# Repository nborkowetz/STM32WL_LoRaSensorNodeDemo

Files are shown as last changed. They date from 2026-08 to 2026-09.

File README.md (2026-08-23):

# STM32WL LoRaWAN Sensor Node

Low-power LoRaWAN sensor node based on the **STM32WL55**, originally designed as a prototype platform for distributed water-monitoring applications.

The original goal was not to build a complete water-quality instrument around a fixed set of probes, but to validate the **overall sensing and communication architecture** first: a battery-powered node, generic sensor interfaces, LoRaWAN connectivity, a local gateway and a self-hosted backend.

Water monitoring may involve very different sensors and analog front-ends depending on the quantity being measured. For this reason, the sensing layer is intentionally kept generic while the project focuses on validating the reusable parts of the system.

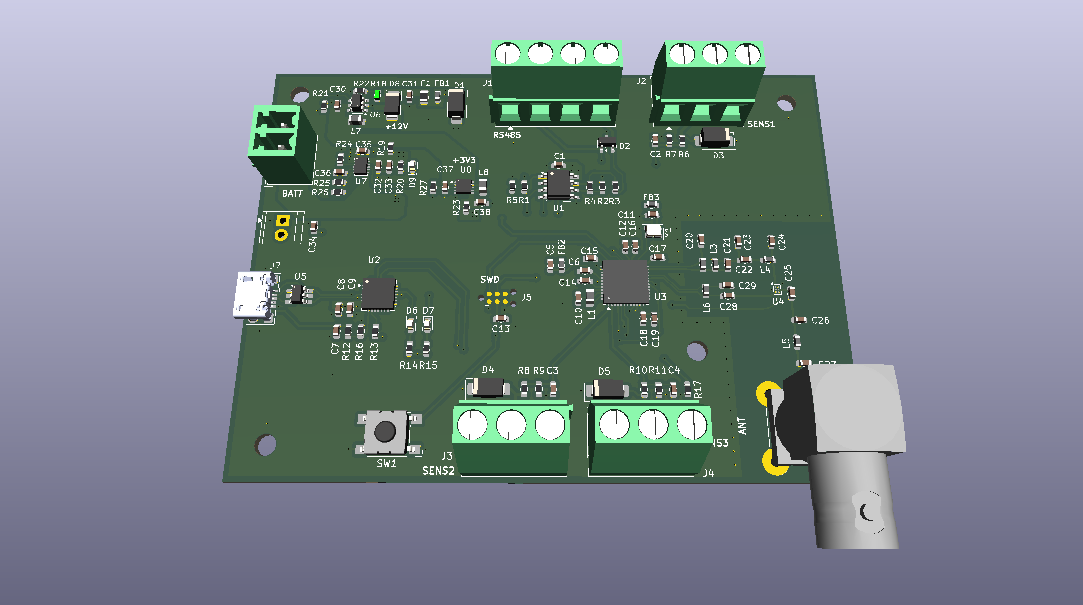
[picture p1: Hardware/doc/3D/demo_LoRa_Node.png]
Board 3D render


## Concept

The prototype is intended as a test platform for the complete data path:

```text
Sensor / External AFE
        |
   Analog / RS-485
        |
        v
   STM32WL55 Node
        |
      LoRaWAN
        |
        v
   Dragino Gateway
        |
        v
    ChirpStack
        |
       MQTT
        |
        v
   Backend / Web UI
```

The custom node provides a small set of generic interfaces:

- 3× protected and filtered analog inputs
- RS-485 interface
- Switchable 12 V sensor supply
- STM32WL55 integrated Sub-GHz radio
- USB-UART debug interface
- Battery-powered / low-power operation

Sensor-specific amplification, isolation or signal conditioning can be added externally when required.

This allows the LoRaWAN architecture, power-management strategy and backend to be developed independently from the final choice of water-quality sensors.

## Firmware

The firmware is being developed around a low-power, event-driven architecture with:

- periodic sensor acquisition
- timer-triggered ADC sampling with DMA
- digital filtering / processing
- asynchronous UART / RS-485 communication
- sensor power sequencing and warm-up
- deep-sleep and periodic wake-up
- periodic LoRaWAN uplinks
- UART debug console
- error handling and watchdog supervision

Typical measurement cycle:

```text
Sleep -> Sensor ON -> Warm-up -> Acquire -> Process
      -> Sensor OFF -> LoRaWAN TX (if scheduled) -> Sleep
```

Firmware development and LoRaWAN validation are currently performed using an **STM32WL55 development board**. The custom PCB has been designed but has not yet been fabricated.

Synthetic sensor values can be injected during development to validate payload generation and the complete communication path without depending on the final sensing hardware.

## LoRaWAN Infrastructure

A second goal of the project is to make the LoRaWAN test environment **reproducible and easy to deploy**, instead of relying on a manually configured development machine.

The planned local infrastructure consists of:

- Dragino LoRaWAN gateway
- ChirpStack network server
- Mosquitto MQTT broker
- containerized deployment with Docker Compose
- deployment / provisioning scripts
- Python / FastAPI backend for receiving, storing and visualizing measurements

The intended workflow is:

```text
docker compose up
        |
        v
ChirpStack + MQTT services
        |
        v
Automated provisioning
        |
        v
Gateway / device registration
        |
        v
End-to-end LoRaWAN test
```

Configuration files and scripts are kept in the repository so that the test environment can be recreated from a clean machine with minimal manual configuration.

The backend consumes application data exposed by ChirpStack through MQTT; the STM32 node itself only produces the application payload and remains independent from MQTT or the backend implementation.

## Repository Structure

```text
.
├── Hardware/          # KiCad schematic, PCB and documentation
├── Firmware/          # STM32WL55 firmware
├── Infrastructure/    # ChirpStack / MQTT / Docker deployment
├── Tools/             # Python utilities and provisioning tools
└── README.md
```

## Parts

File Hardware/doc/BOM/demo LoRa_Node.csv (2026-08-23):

Id | Designator | Footprint | Quantity | Designation | Supplier and ref
1 | BT1 | PhoenixContact_MCV_1,5_2-G-3.81_1x02_P3.81mm_Vertical | 1 | Battery
2 | C1, C2, C3, C4, C6, C7, C9, C11, C13, C14, C15, C16, C17, C18, C35, C36 | C_0603_1608Metric | 16 | 100n
3 | C5, C8, C10, C19, C32 | C_0603_1608Metric | 5 | 4u7
4 | C12 | C_0603_1608Metric | 1 | 470n
5 | C20, C22, C25 | C_0603_1608Metric | 3 | 68p
6 | C21 | C_0603_1608Metric | 1 | 4p3
7 | C23 | C_0603_1608Metric | 1 | 15p
8 | C24 | C_0603_1608Metric | 1 | 5p6
9 | C26, C27 | C_0603_1608Metric | 2 | 6p8
10 | C28 | C_0603_1608Metric | 1 | 3p6
11 | C29 | C_0603_1608Metric | 1 | 4p7
12 | C30, C31, C33, C38 | C_0603_1608Metric | 4 | 22u
13 | C34, C37 | C_0603_1608Metric | 2 | 10u
14 | D1 | D_SMA | 1 | SMAJ12CA
15 | D2 | SOT-23 | 1 | SM712_SOT23
16 | D3, D4, D5 | D_SMA | 3 | SMAJ6.0CA
17 | D6, D7, D9 | LED_0603_1608Metric | 3 | LED
18 | D8 | D_SOD-128 | 1 | SB120
19 | F1 | Fuse_0805_2012Metric | 1 | 200mA
20 | FB1, FB2, FB3 | L_0603_1608Metric | 3 | 600Ohm@10MHz
21 | J1 | TerminalBlock_Phoenix_MKDS-1,5-4-5.08_1x04_P5.08mm_Horizontal | 1 | Screw_Terminal_01x04
22 | J2, J3, J4 | TerminalBlock_Phoenix_MKDS-1,5-3-5.08_1x03_P5.08mm_Horizontal | 3 | Screw_Terminal_01x03
23 | J6 | BNC_TEConnectivity_1478035_Horizontal | 1 | Conn_Coaxial
24 | J7 | Amphenol usb micro connector | 1 | USB_B_Micro
25 | J8 | TerminalBlock_TE_282834-2_1x02_P2.54mm_Horizontal | 1 | Conn_01x02
26 | L1 | L_0805_2012Metric | 1 | 15u
27 | L2 | L_0603_1608Metric | 1 | 56n
28 | L3 | L_0603_1608Metric | 1 | 6n8
29 | L4, L5 | L_0603_1608Metric | 2 | 16n
30 | L6 | L_0603_1608Metric | 1 | 33n
31 | L7 | L_0805_2012Metric | 1 | 10u
32 | L8 | L_0805_2012Metric | 1 | 2u2
33 | R1, R5, R6, R8, R10, R22 | R_0603_1608Metric | 6 | 10k
34 | R2, R3 | R_0603_1608Metric | 2 | 10
35 | R4 | R_0603_1608Metric | 1 | 120
36 | R7, R9, R11 | R_0603_1608Metric | 3 | 16k2
37 | R12 | R_0603_1608Metric | 1 | 46k4
38 | R13, R14, R15, R20, R24 | R_0603_1608Metric | 5 | 1k
39 | R16, R17, R21, R26 | R_0603_1608Metric | 4 | 100k
40 | R18 | R_0603_1608Metric | 1 | 191k
41 | R19, R23 | R_0603_1608Metric | 2 | 0
42 | R25 | R_0603_1608Metric | 1 | 490k
43 | R27 | R_0603_1608Metric | 1 | 36k5
44 | SW1 | SW_SPST_Omron_B3FS-100xP | 1 | SW_Omron_B3FS
45 | U1 | SOIC-8_3.9x4.9mm_P1.27mm | 1 | THVD1400D
46 | U2 | QFN-28-1EP_5x5mm_P0.5mm_EP3.35x3.35mm | 1 | CP2102N-Axx-xQFN28
47 | U3 | QFN-48-1EP_7x7mm_P0.5mm_EP5.6x5.6mm | 1 | STM32WL55CCUx
48 | U4 | Infineon_PG-TSNP-6-10_0.7x1.1mm_0.7x1.1mm_P0.4mm | 1 | BGS12WN6E6327
49 | U5 | SOT-23-6_Handsoldering | 1 | WE-TVS-82400102
50 | U6 | SOT-23-6 | 1 | MT3608
51 | U7 | WSON-10-1EP_2x3mm_P0.5mm_EP0.84x2.4mm_ThermalVias | 1 | BQ25071
52 | U8 | WSON-10-1EP_2.5x2.5mm_P0.5mm_EP1.2x2mm_ThermalVias | 1 | TPS63900
53 | Y1 | Oscillator_SMD_SeikoEpson_SG210-4Pin_2.5x2.0mm | 1 | SG-210STF 32MHz

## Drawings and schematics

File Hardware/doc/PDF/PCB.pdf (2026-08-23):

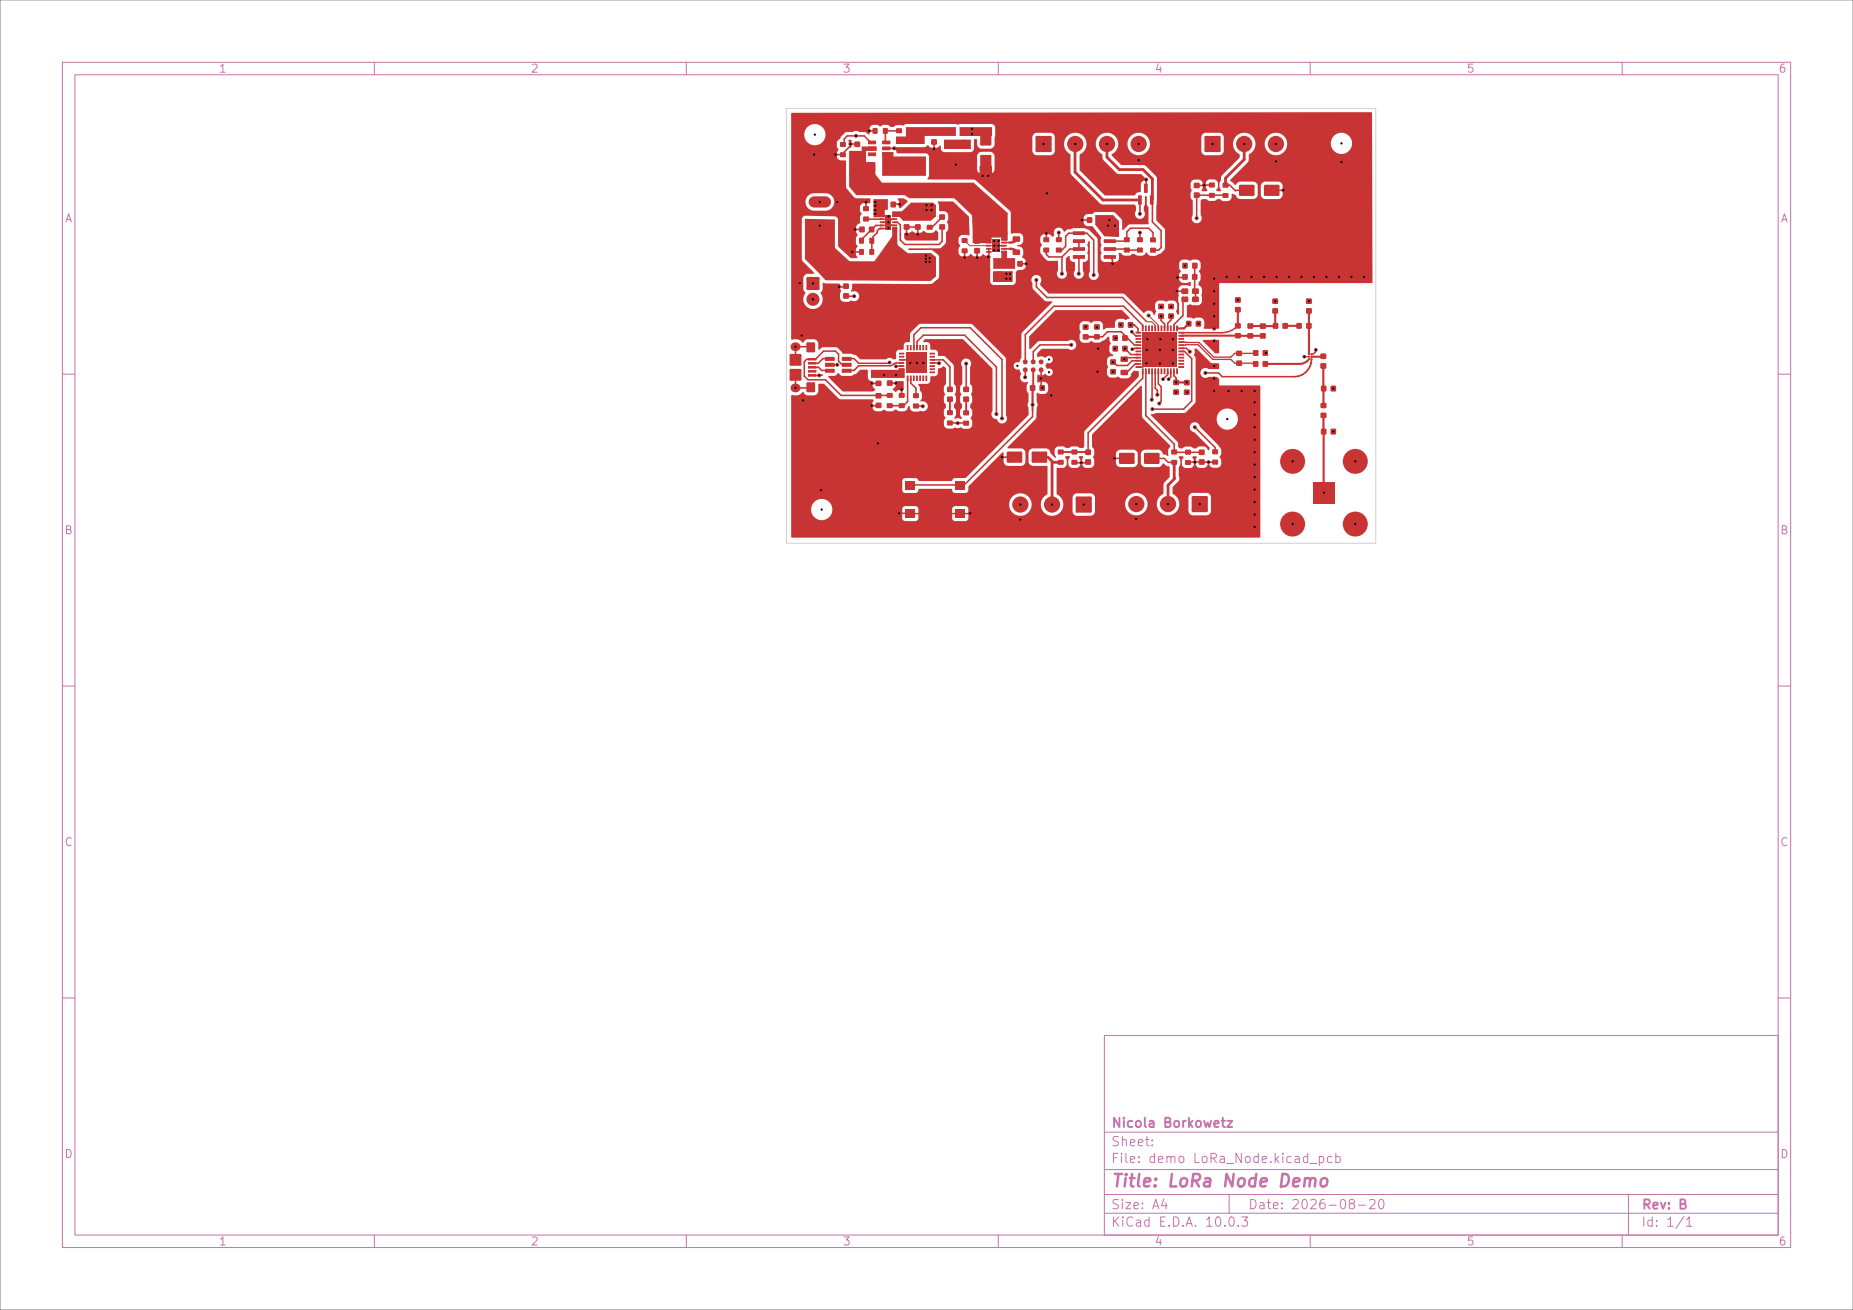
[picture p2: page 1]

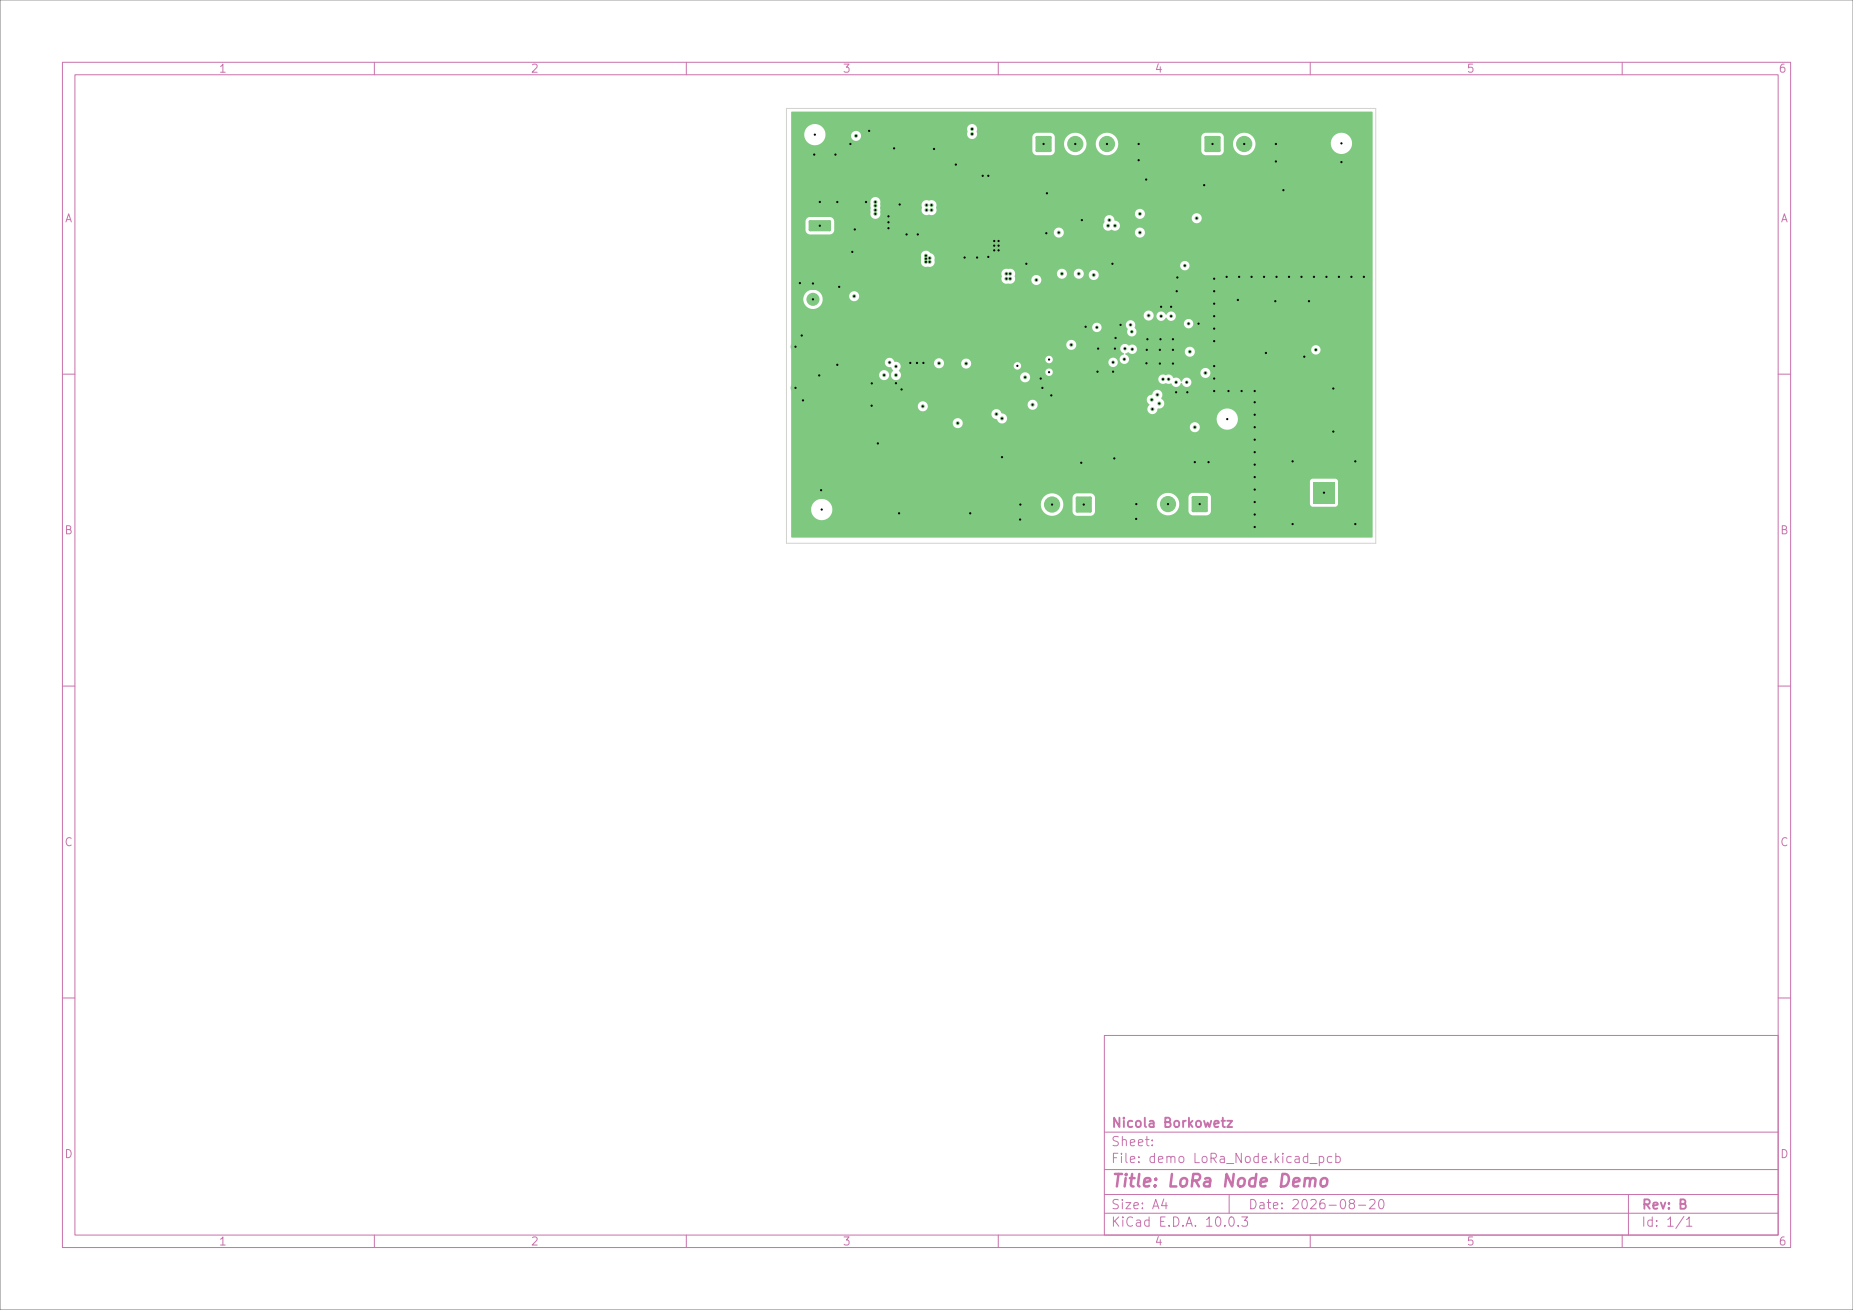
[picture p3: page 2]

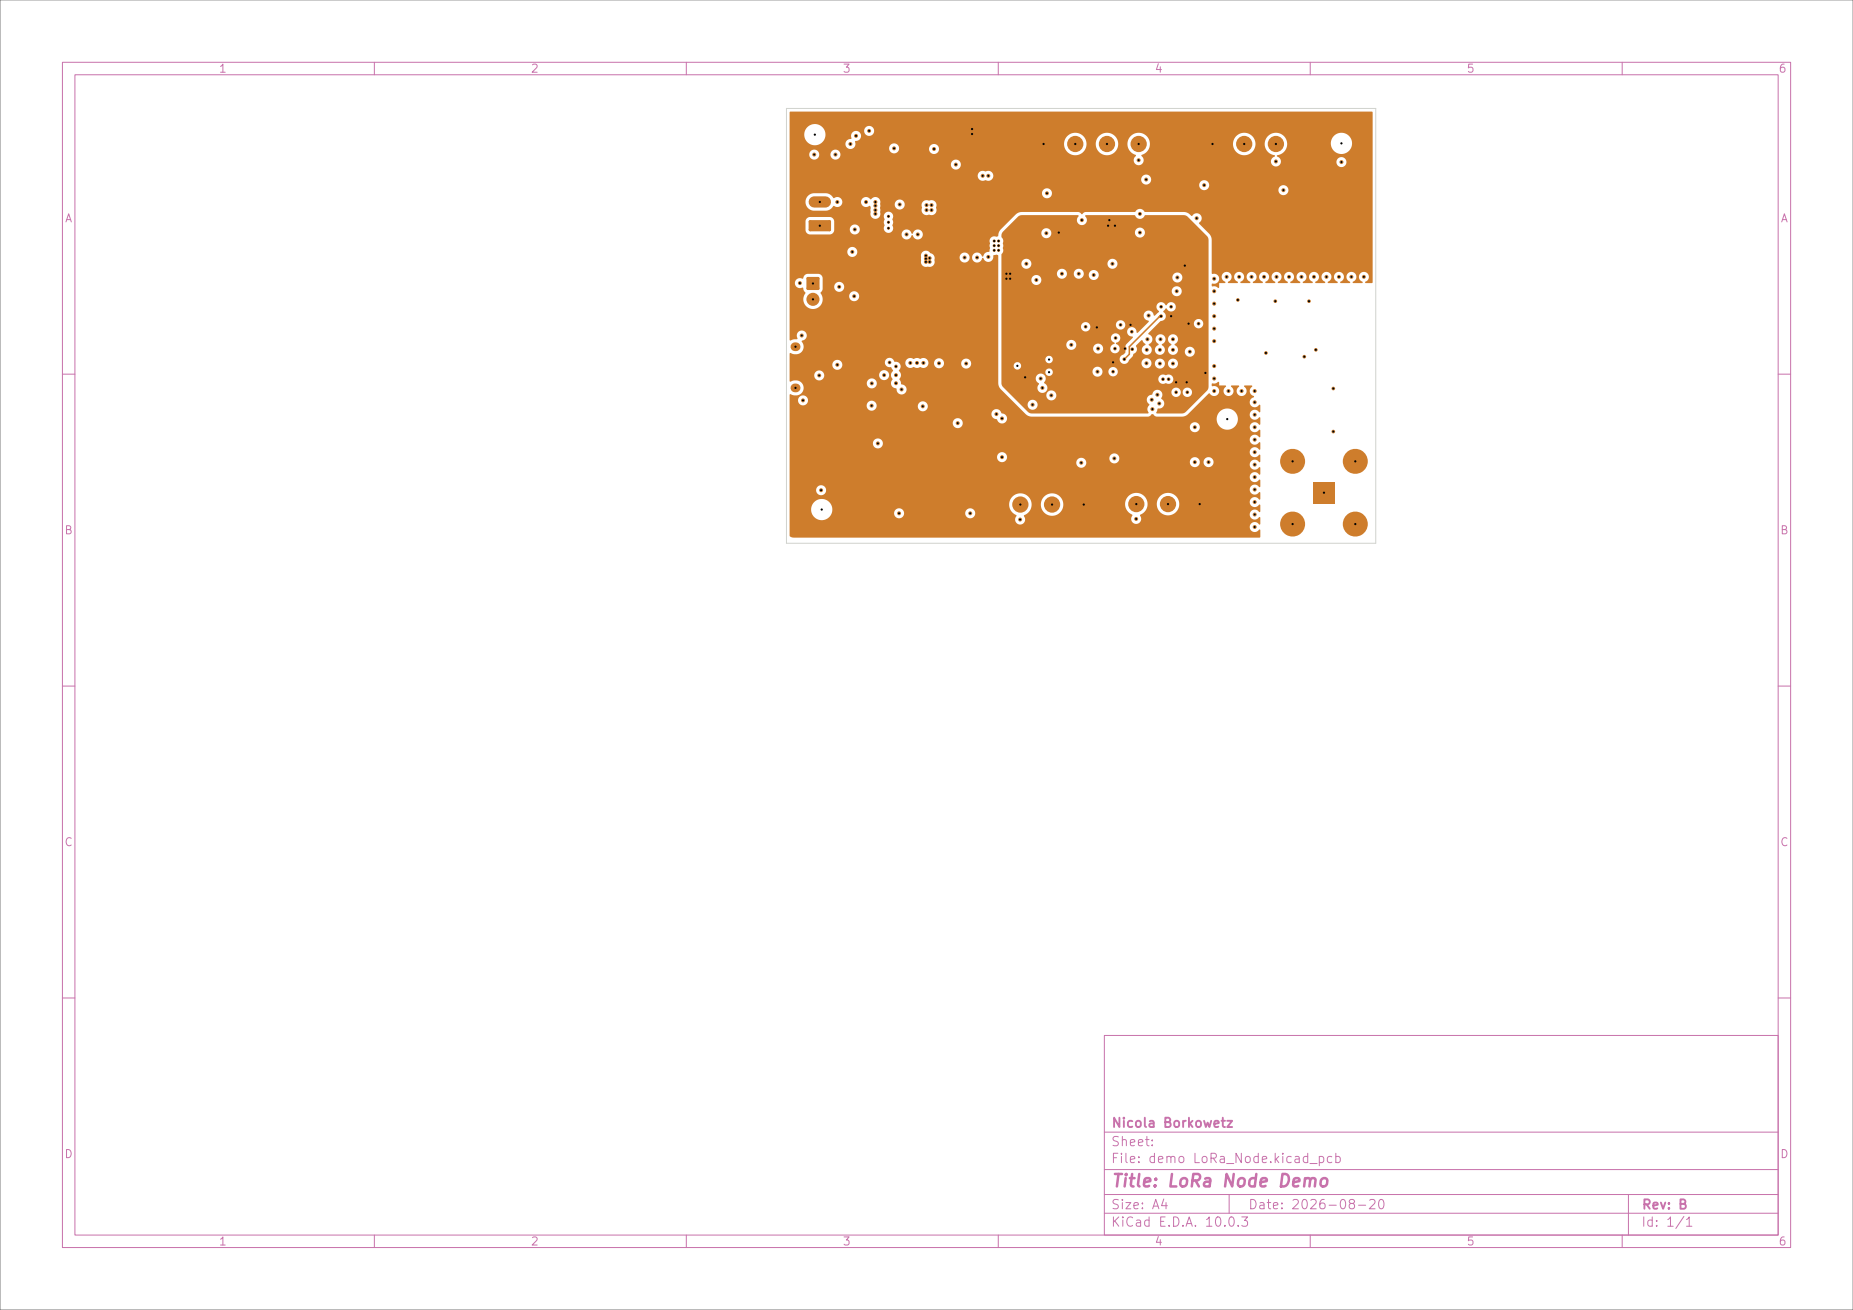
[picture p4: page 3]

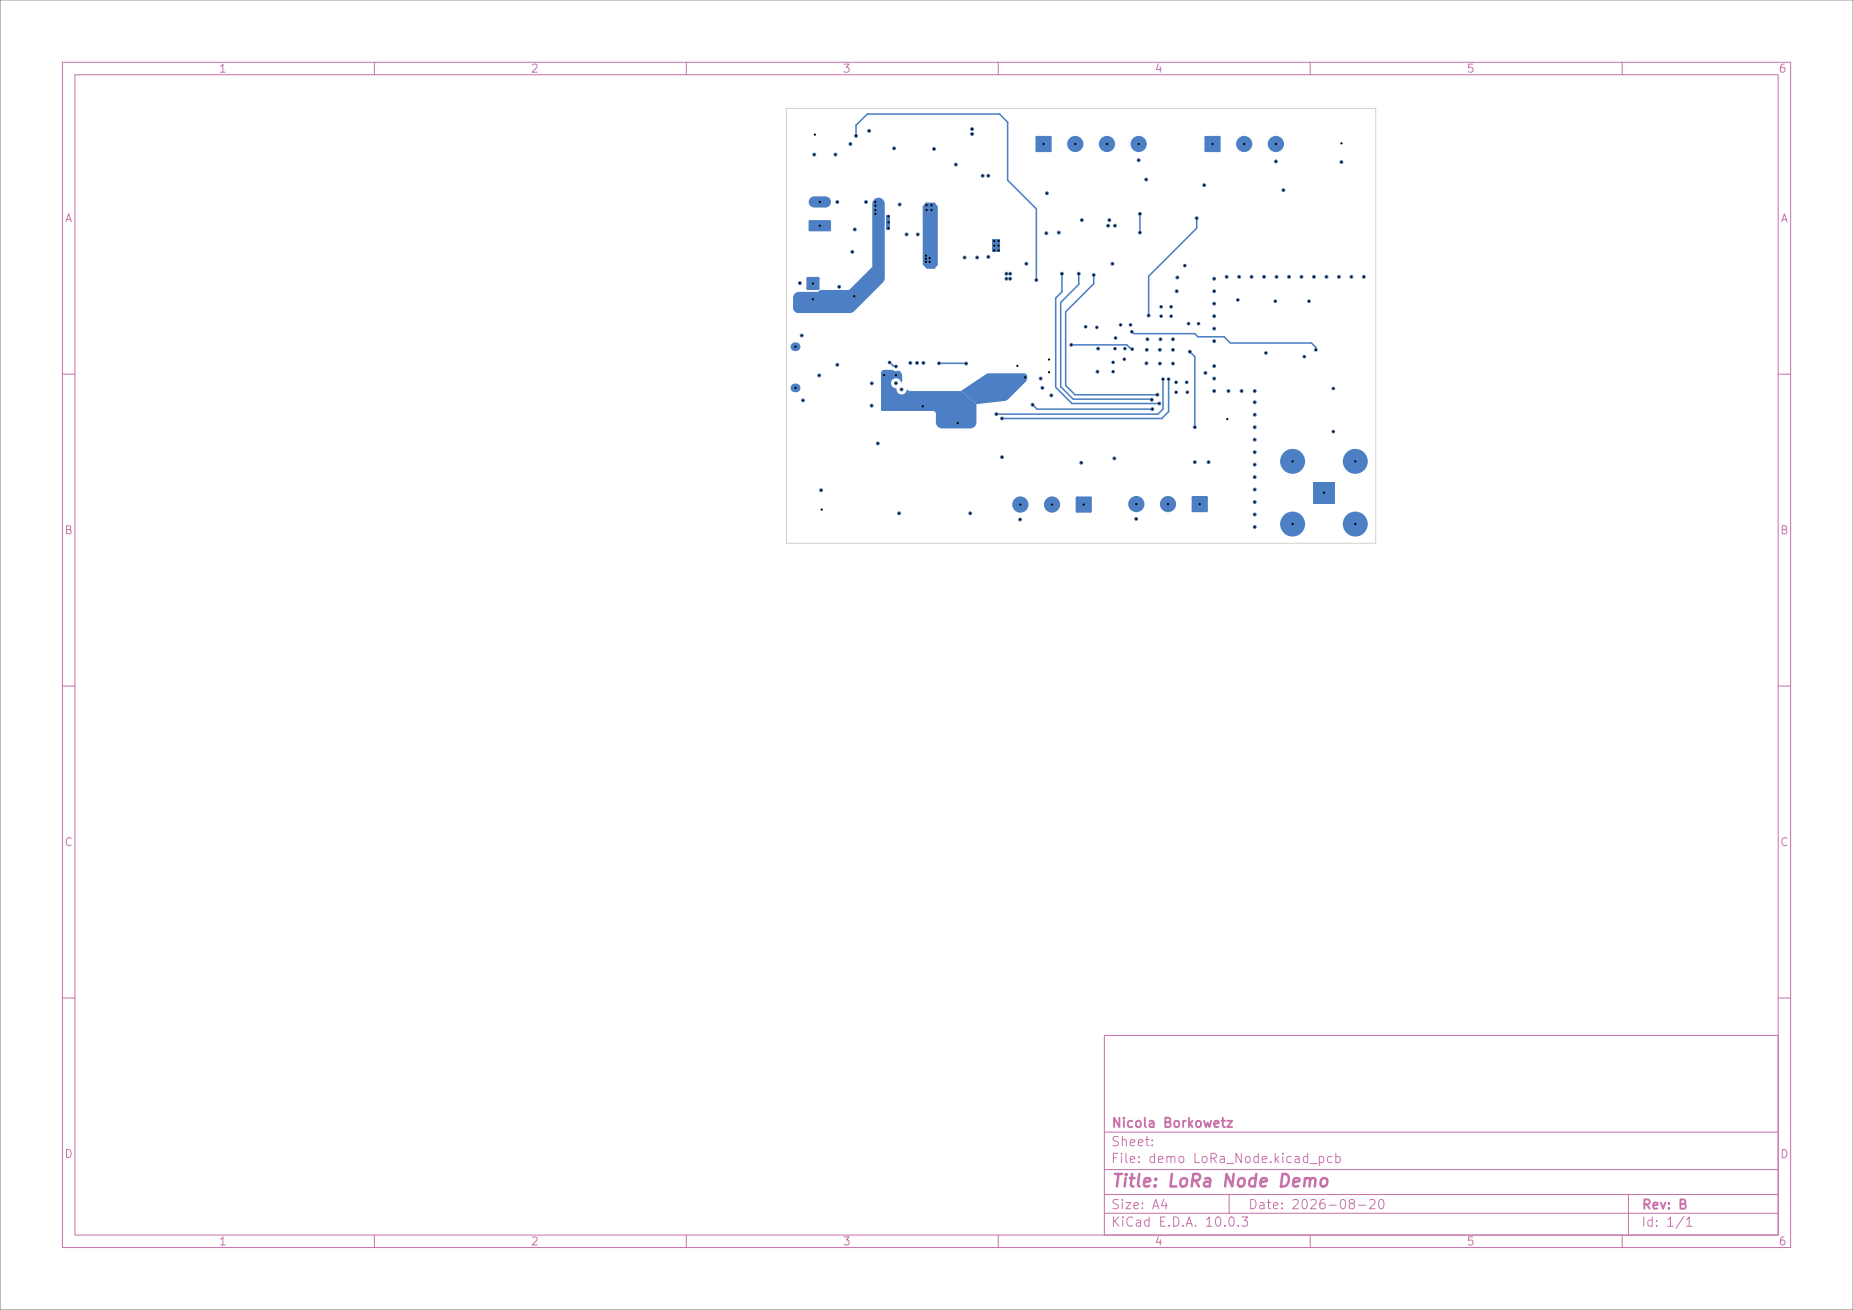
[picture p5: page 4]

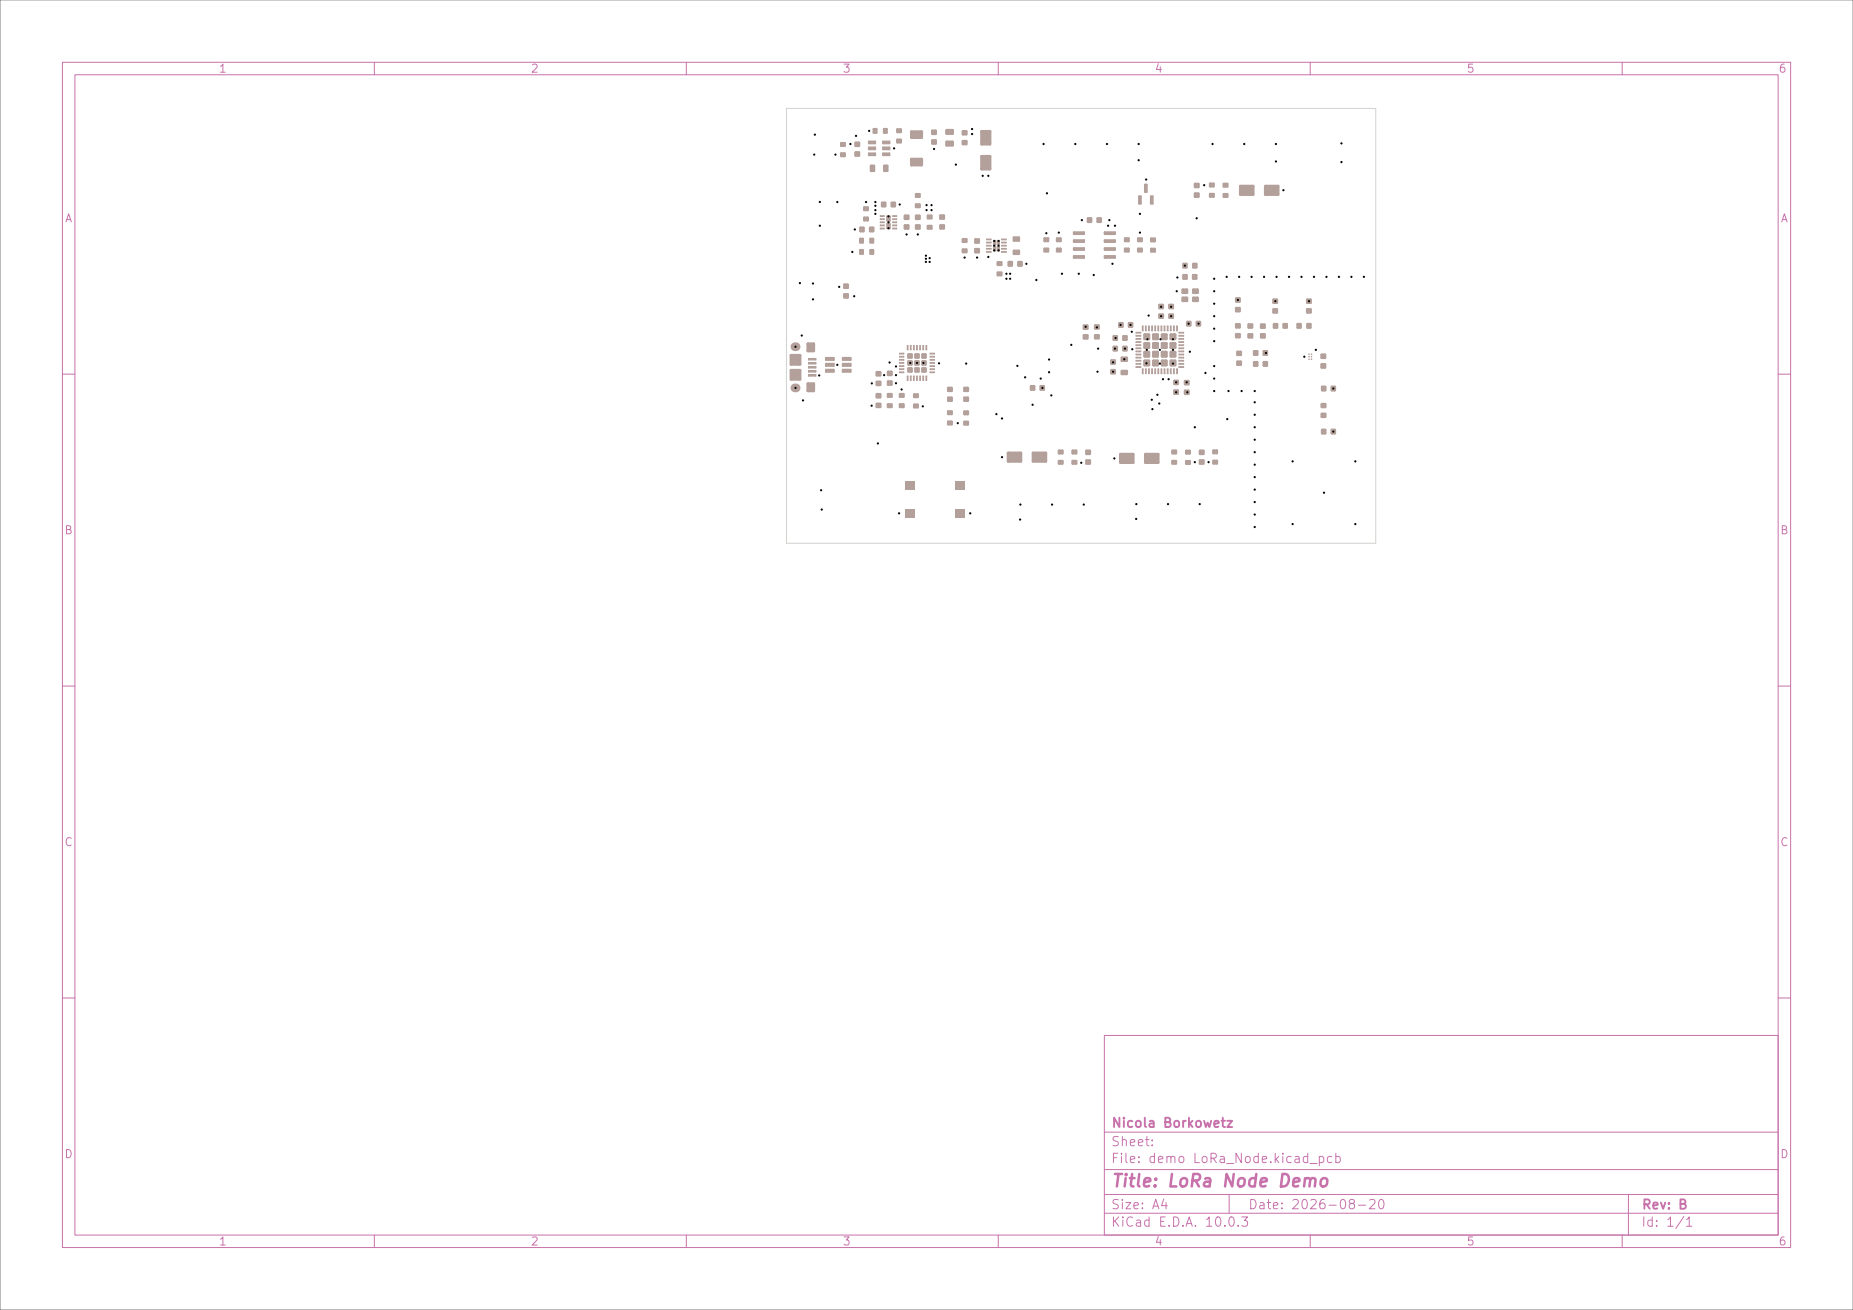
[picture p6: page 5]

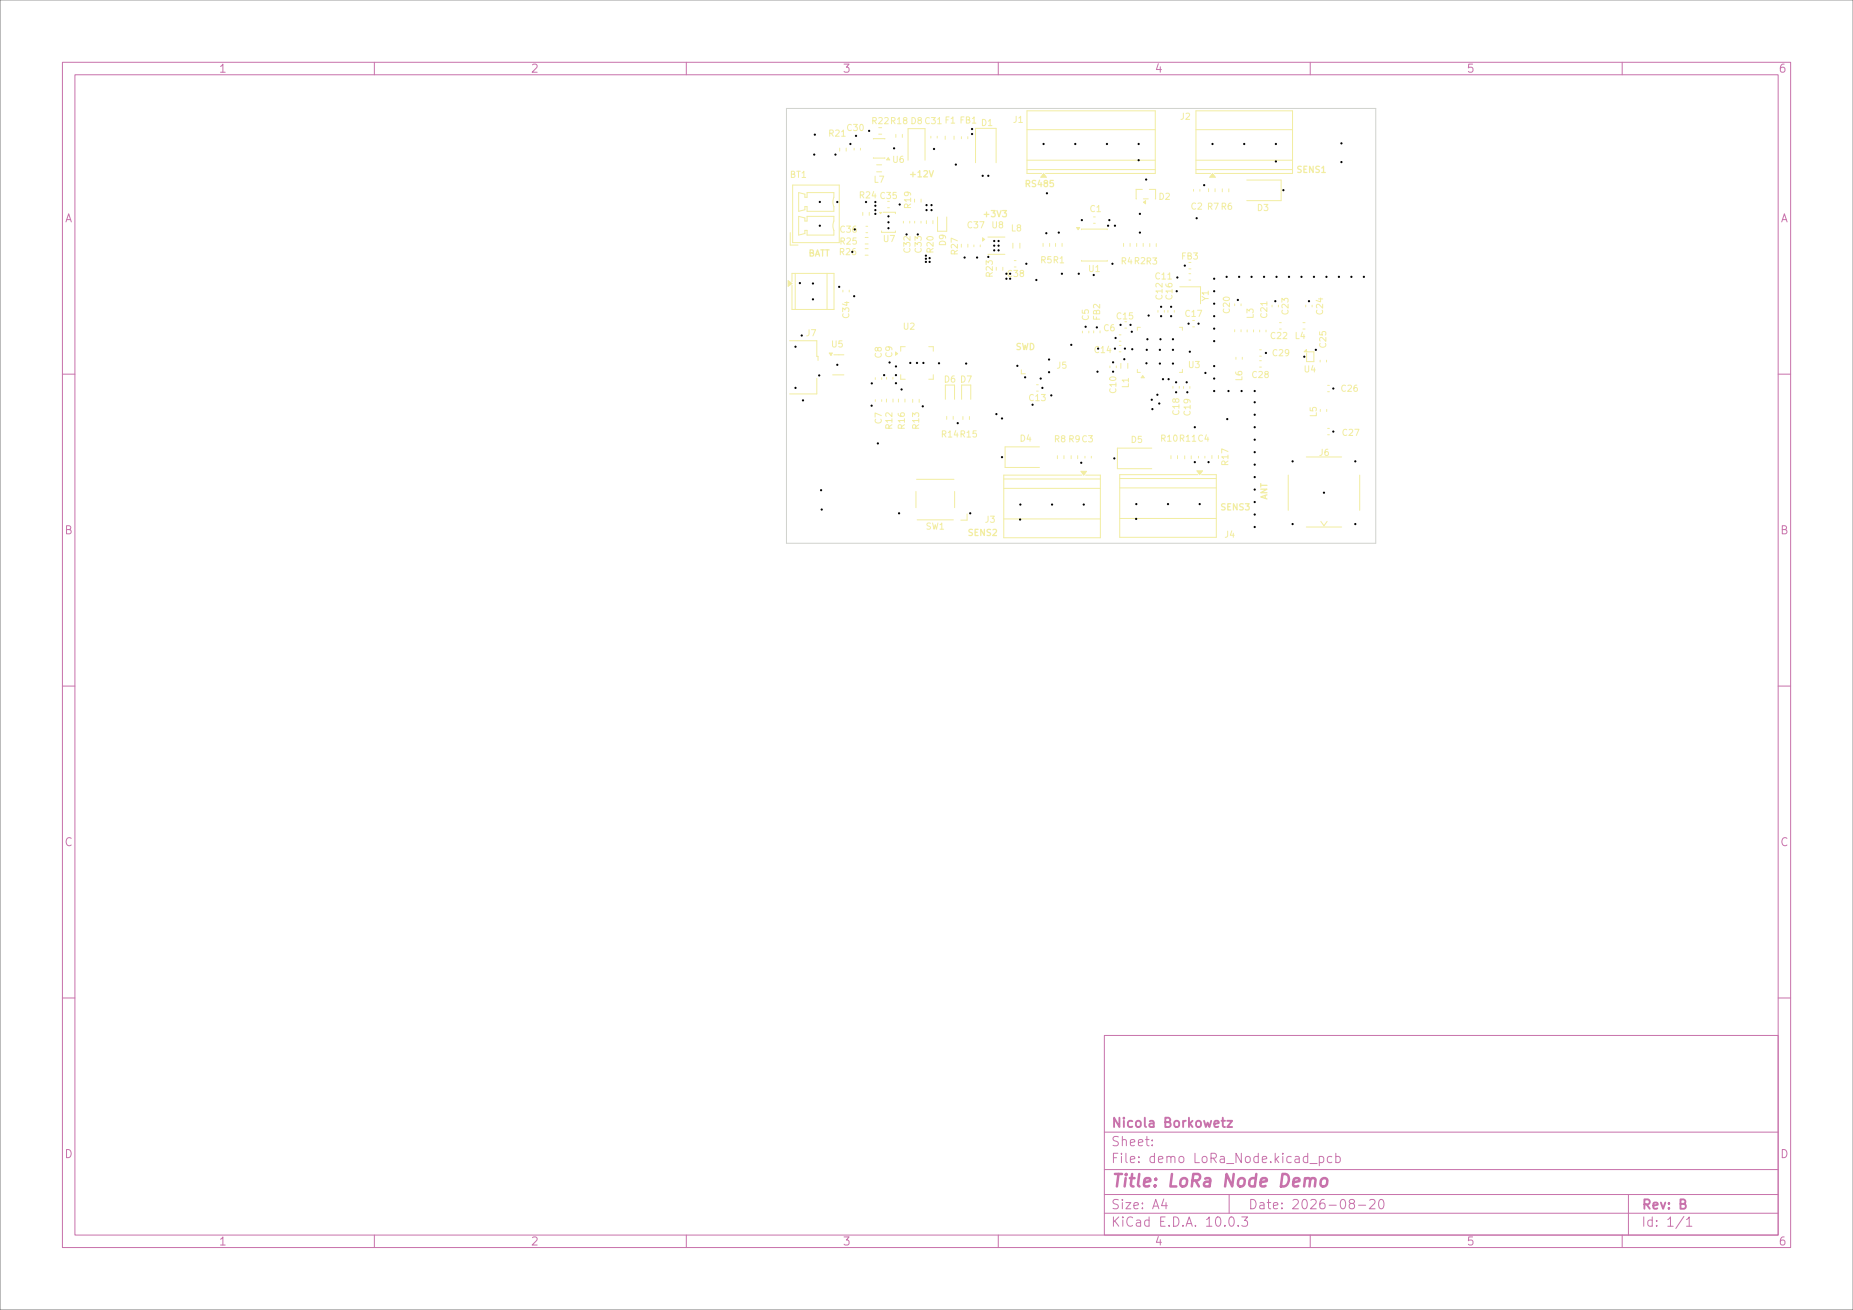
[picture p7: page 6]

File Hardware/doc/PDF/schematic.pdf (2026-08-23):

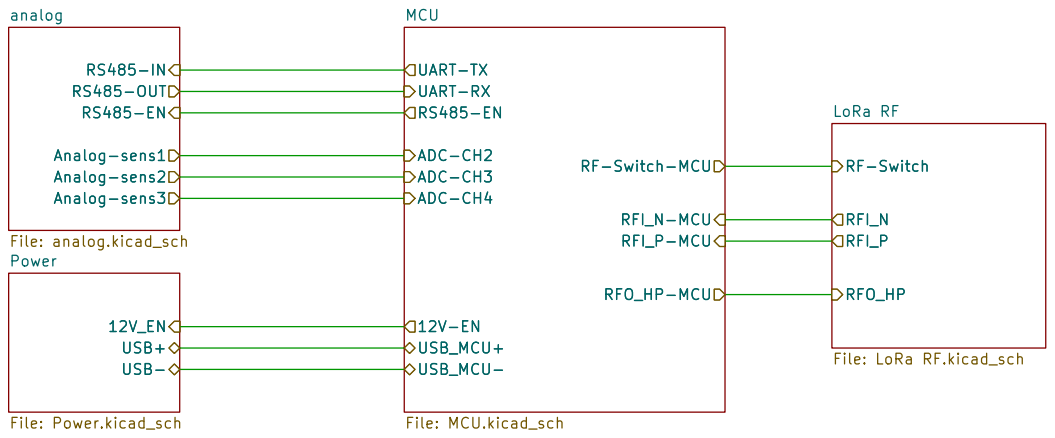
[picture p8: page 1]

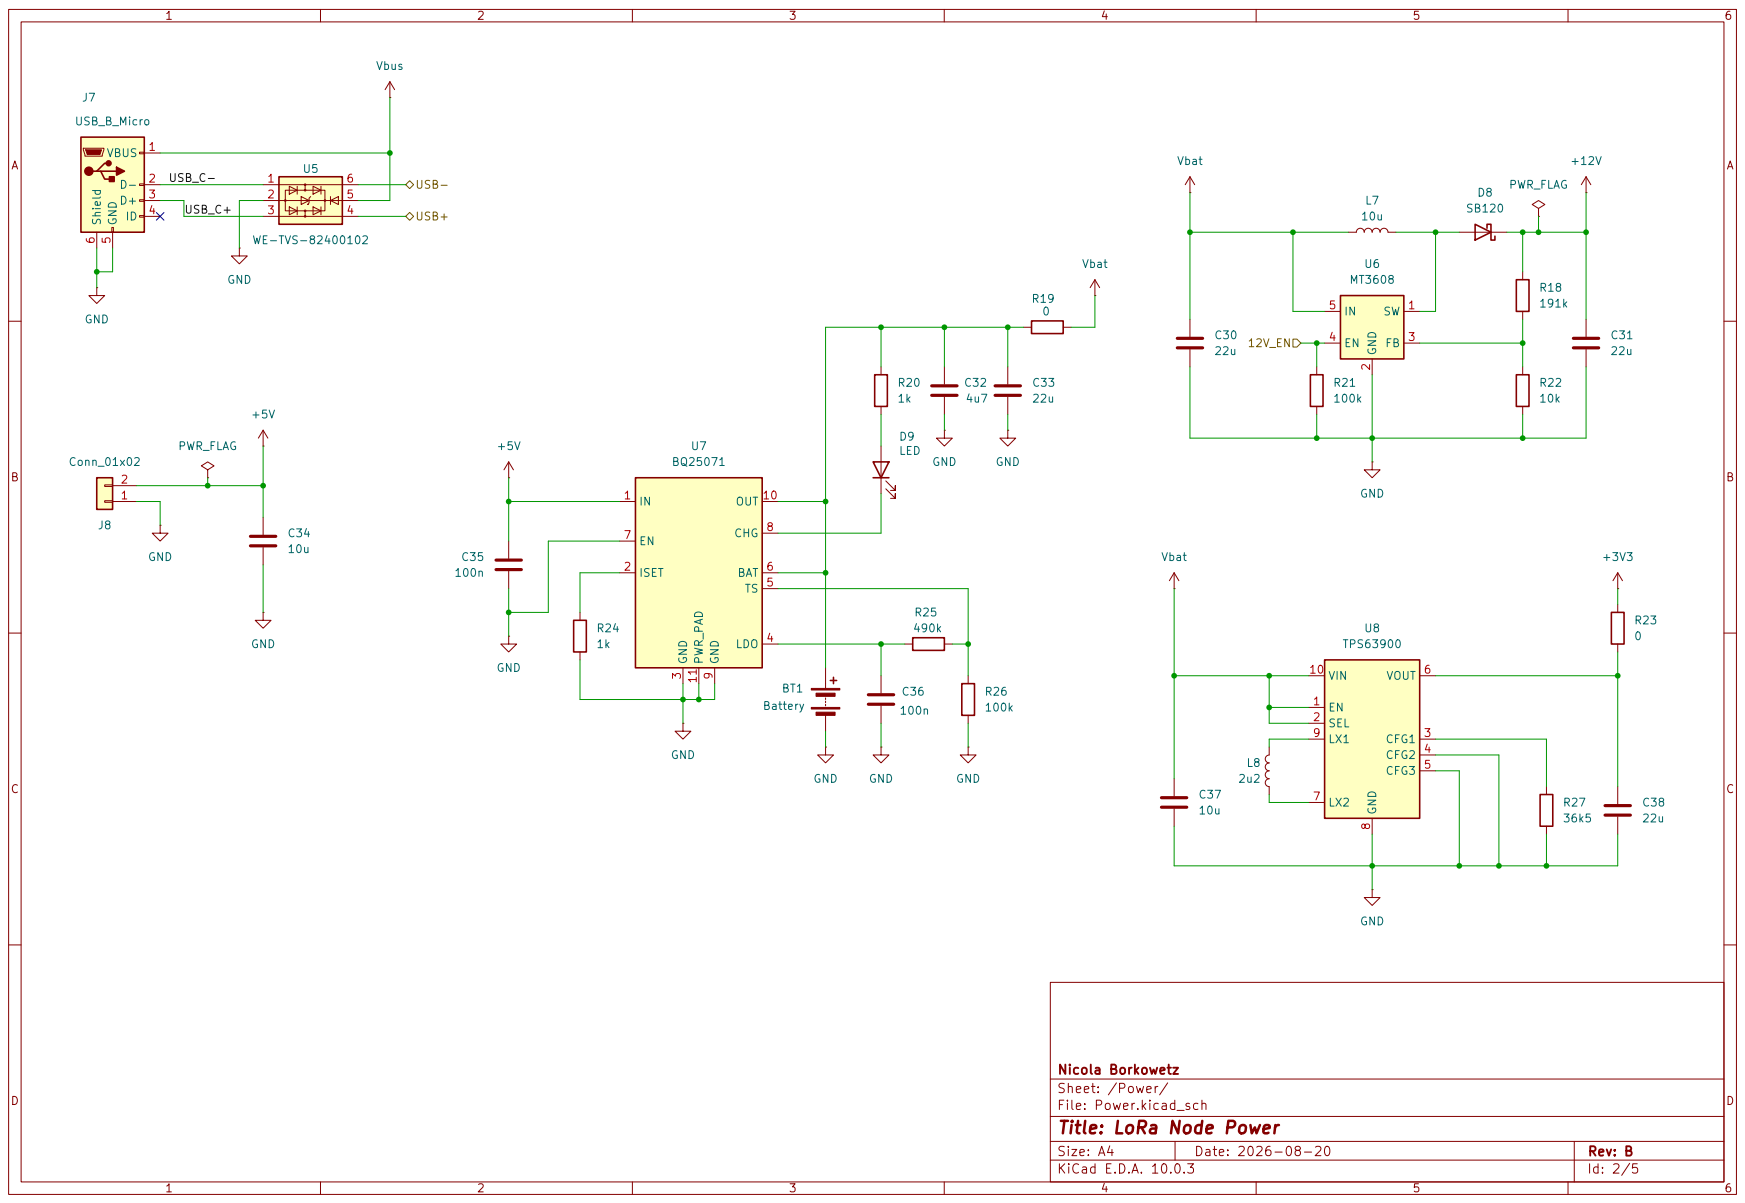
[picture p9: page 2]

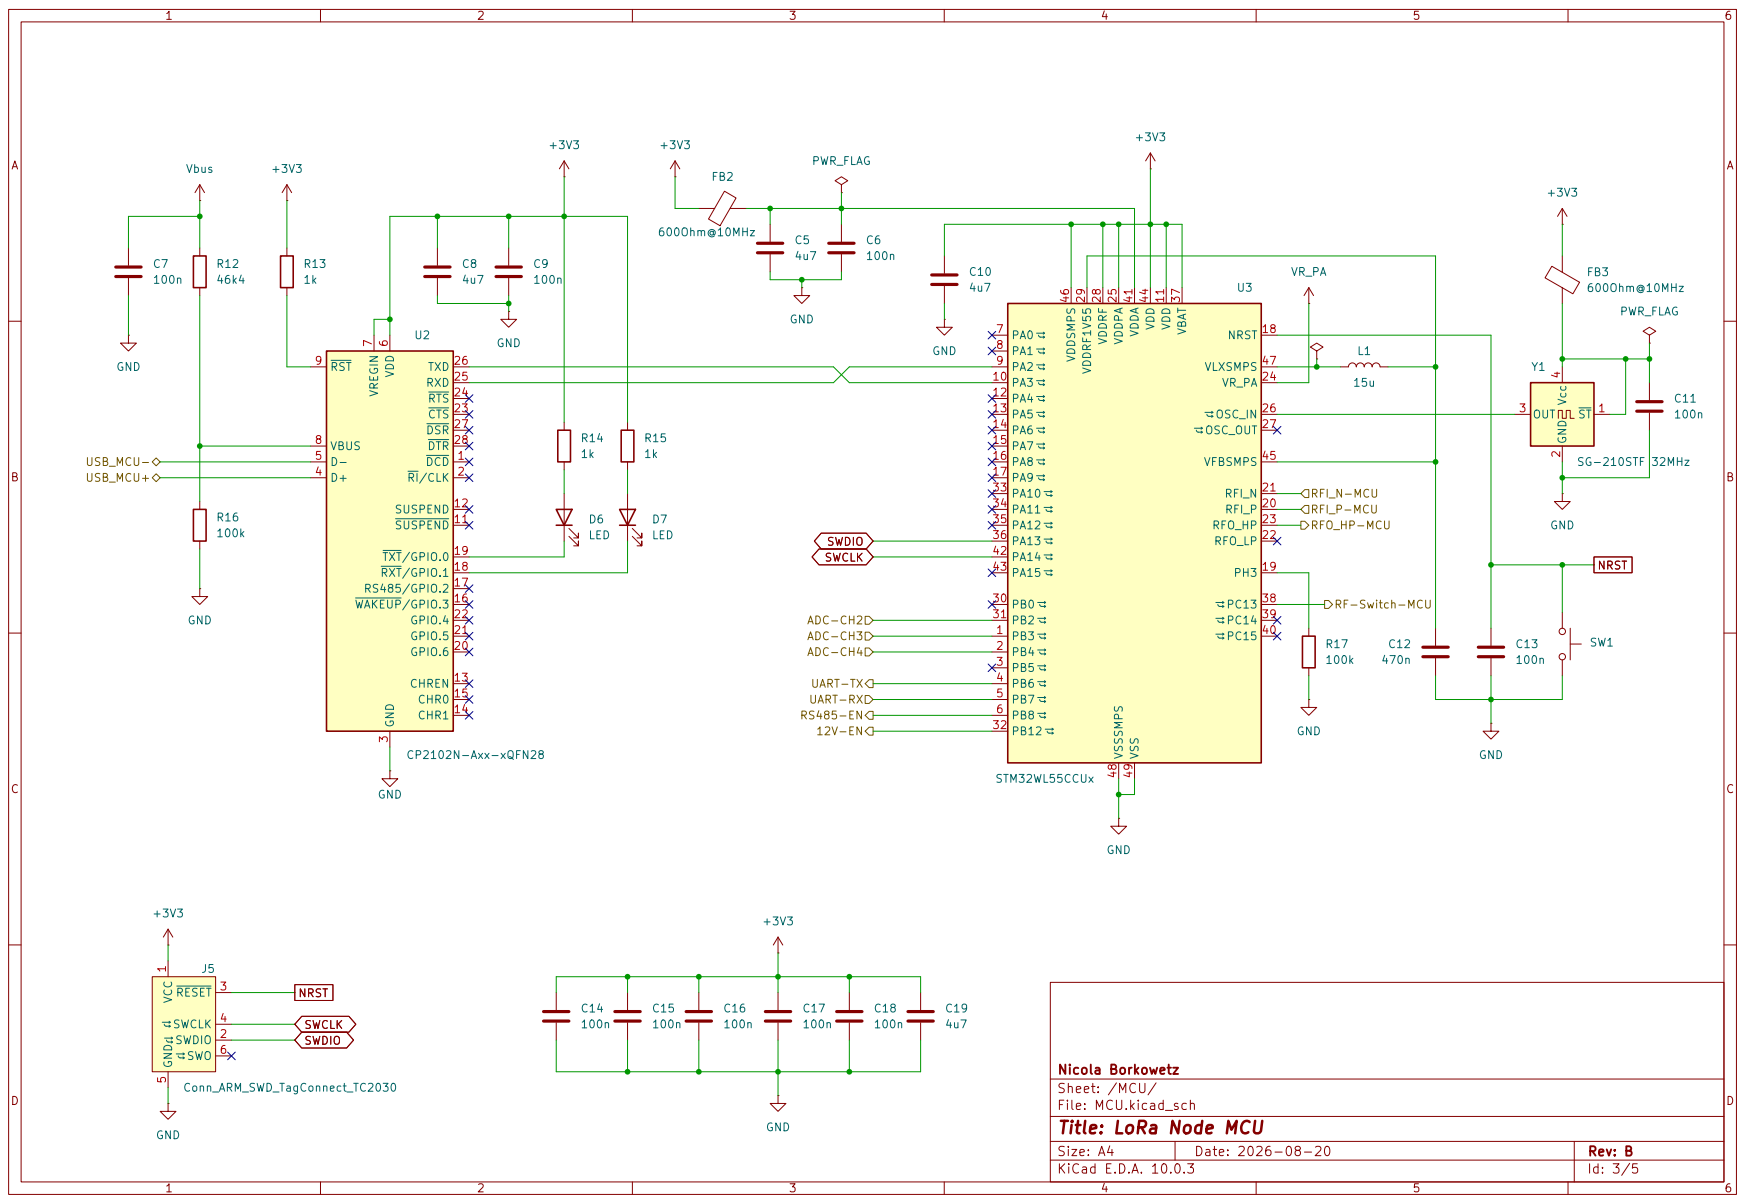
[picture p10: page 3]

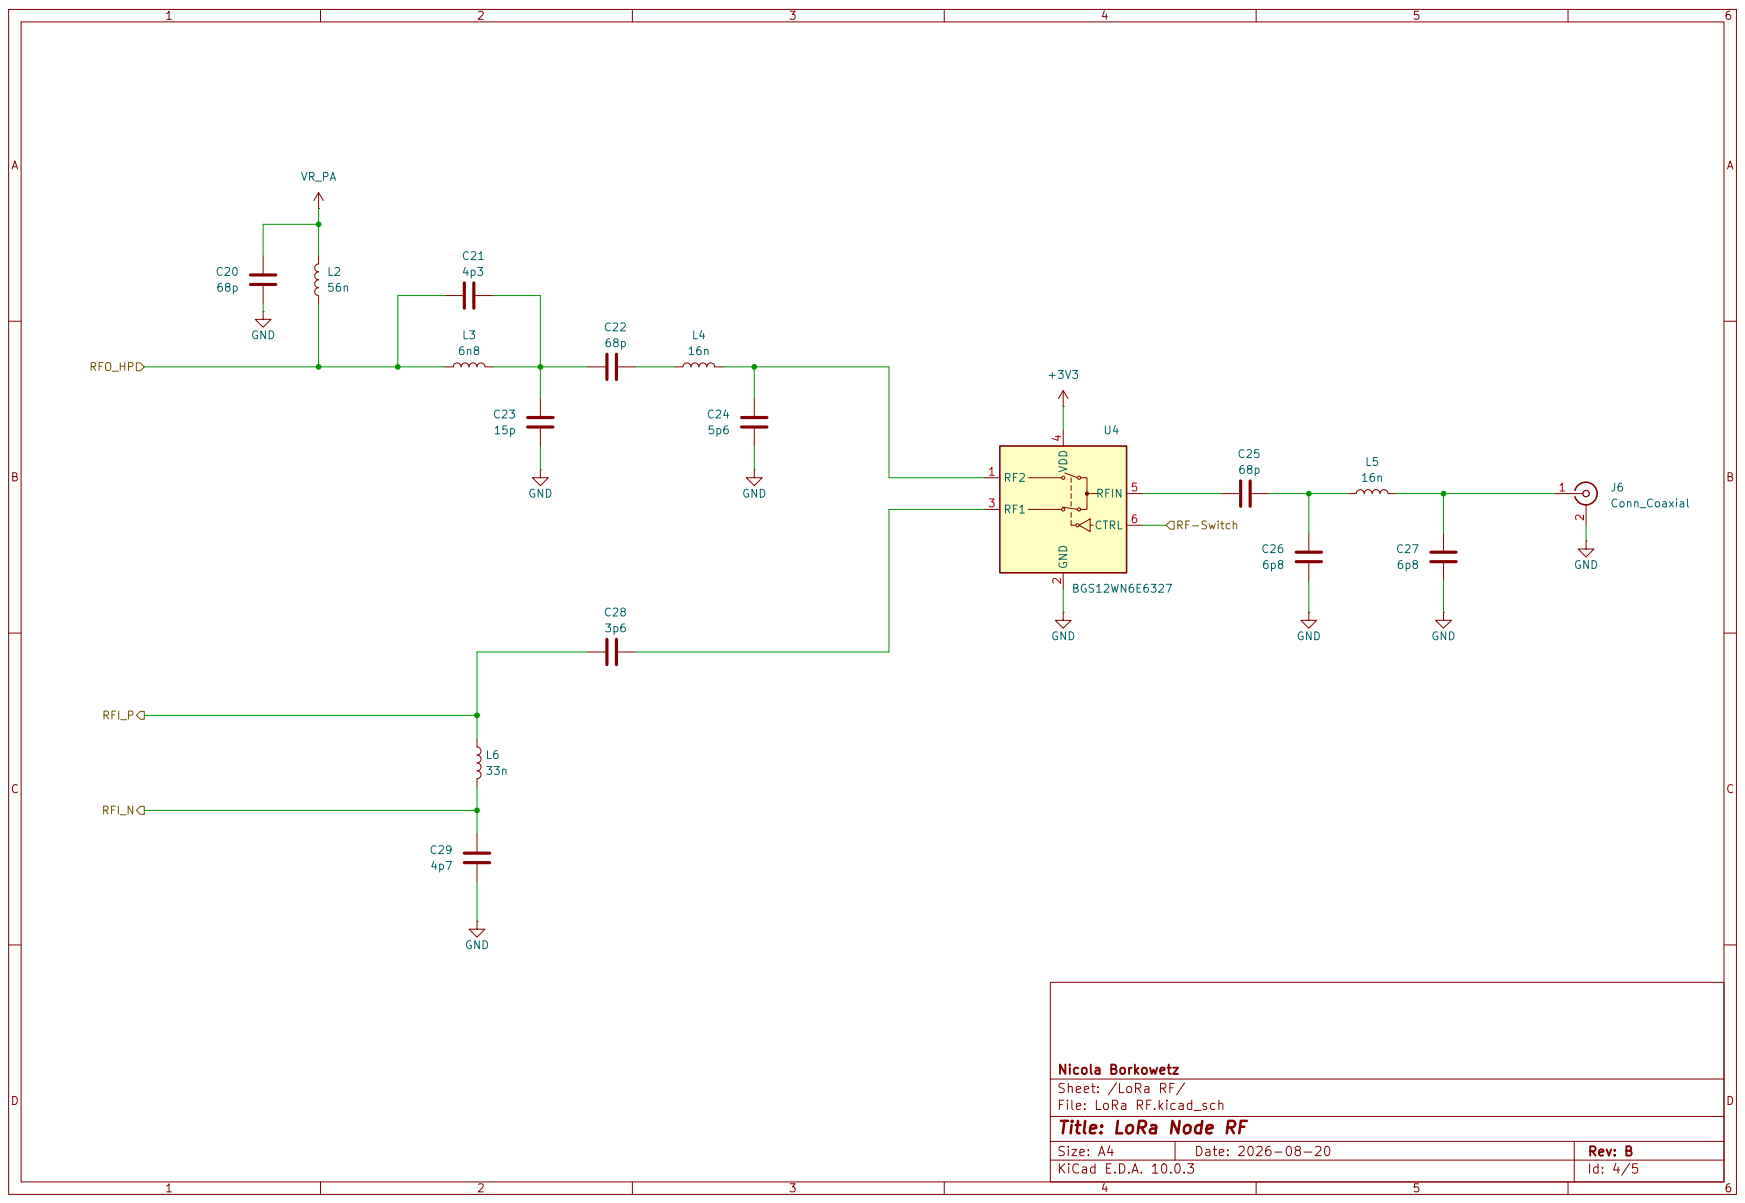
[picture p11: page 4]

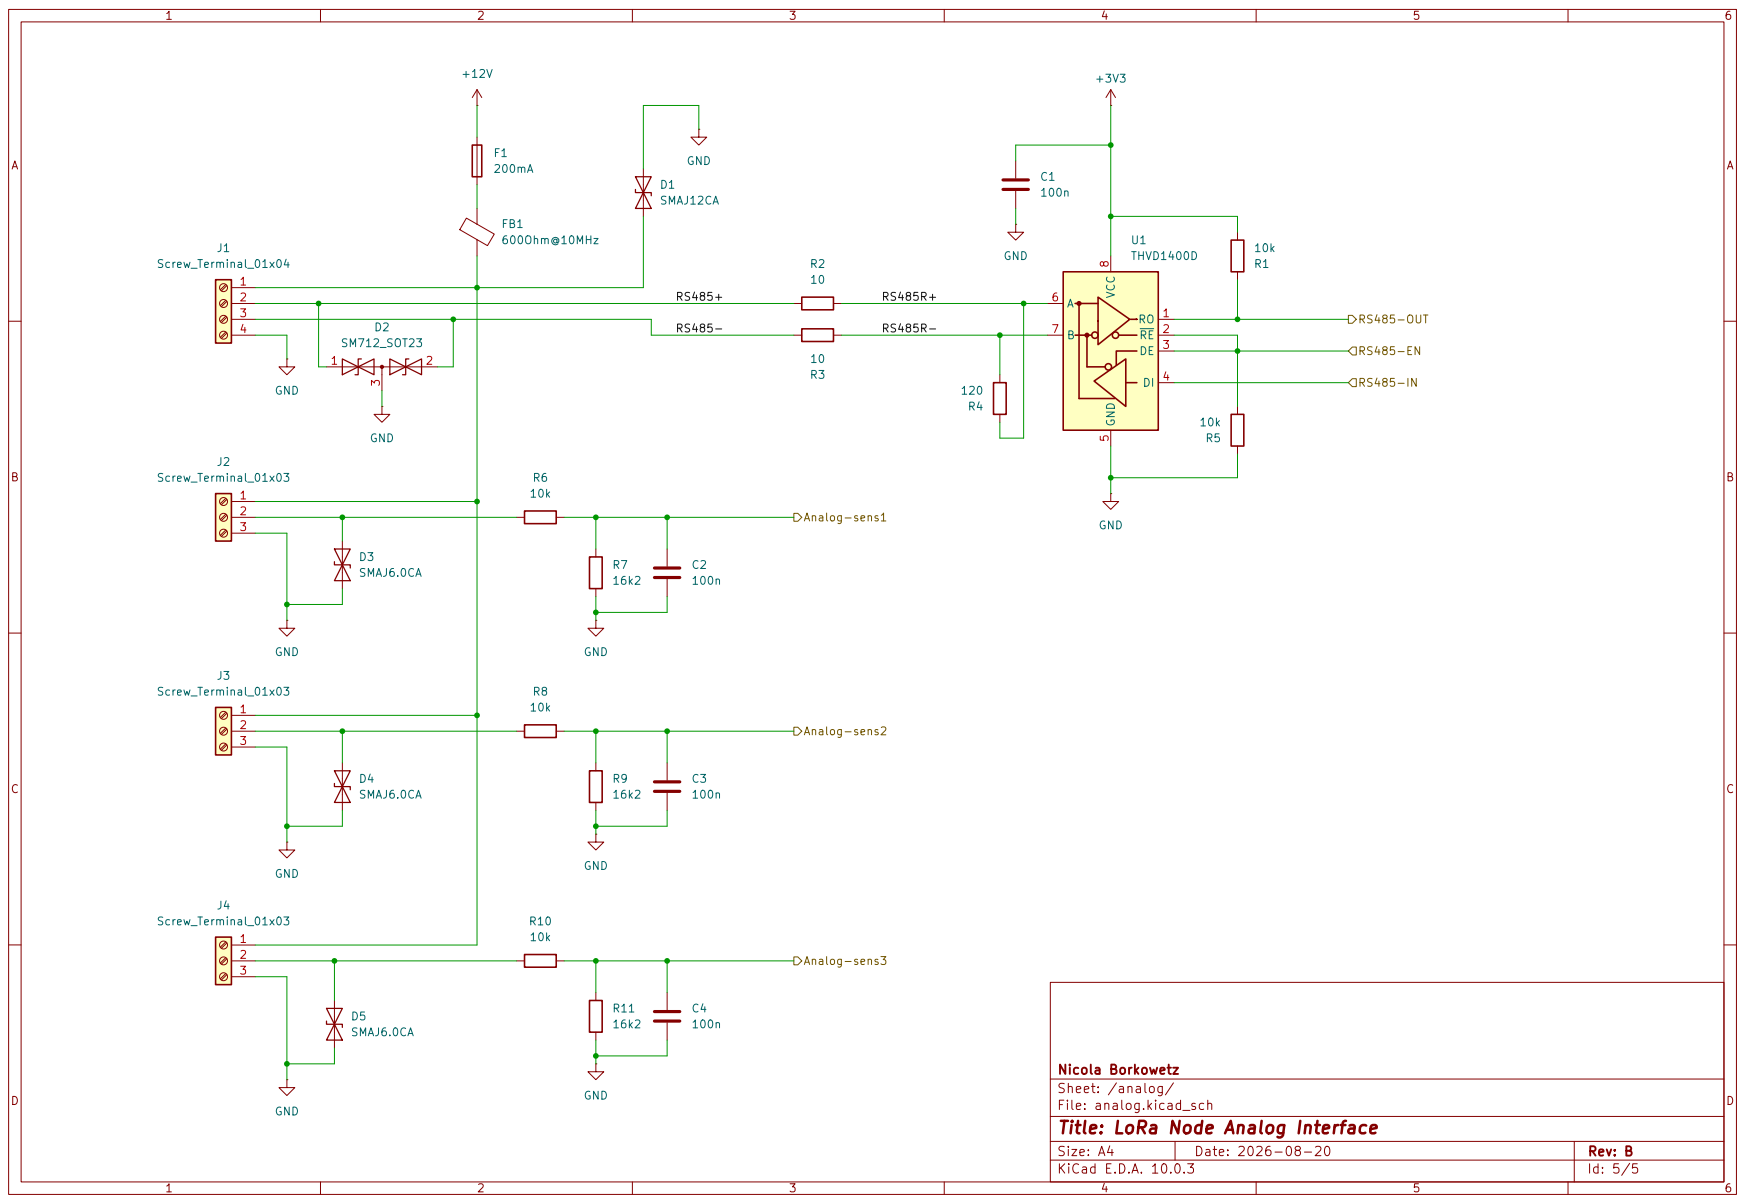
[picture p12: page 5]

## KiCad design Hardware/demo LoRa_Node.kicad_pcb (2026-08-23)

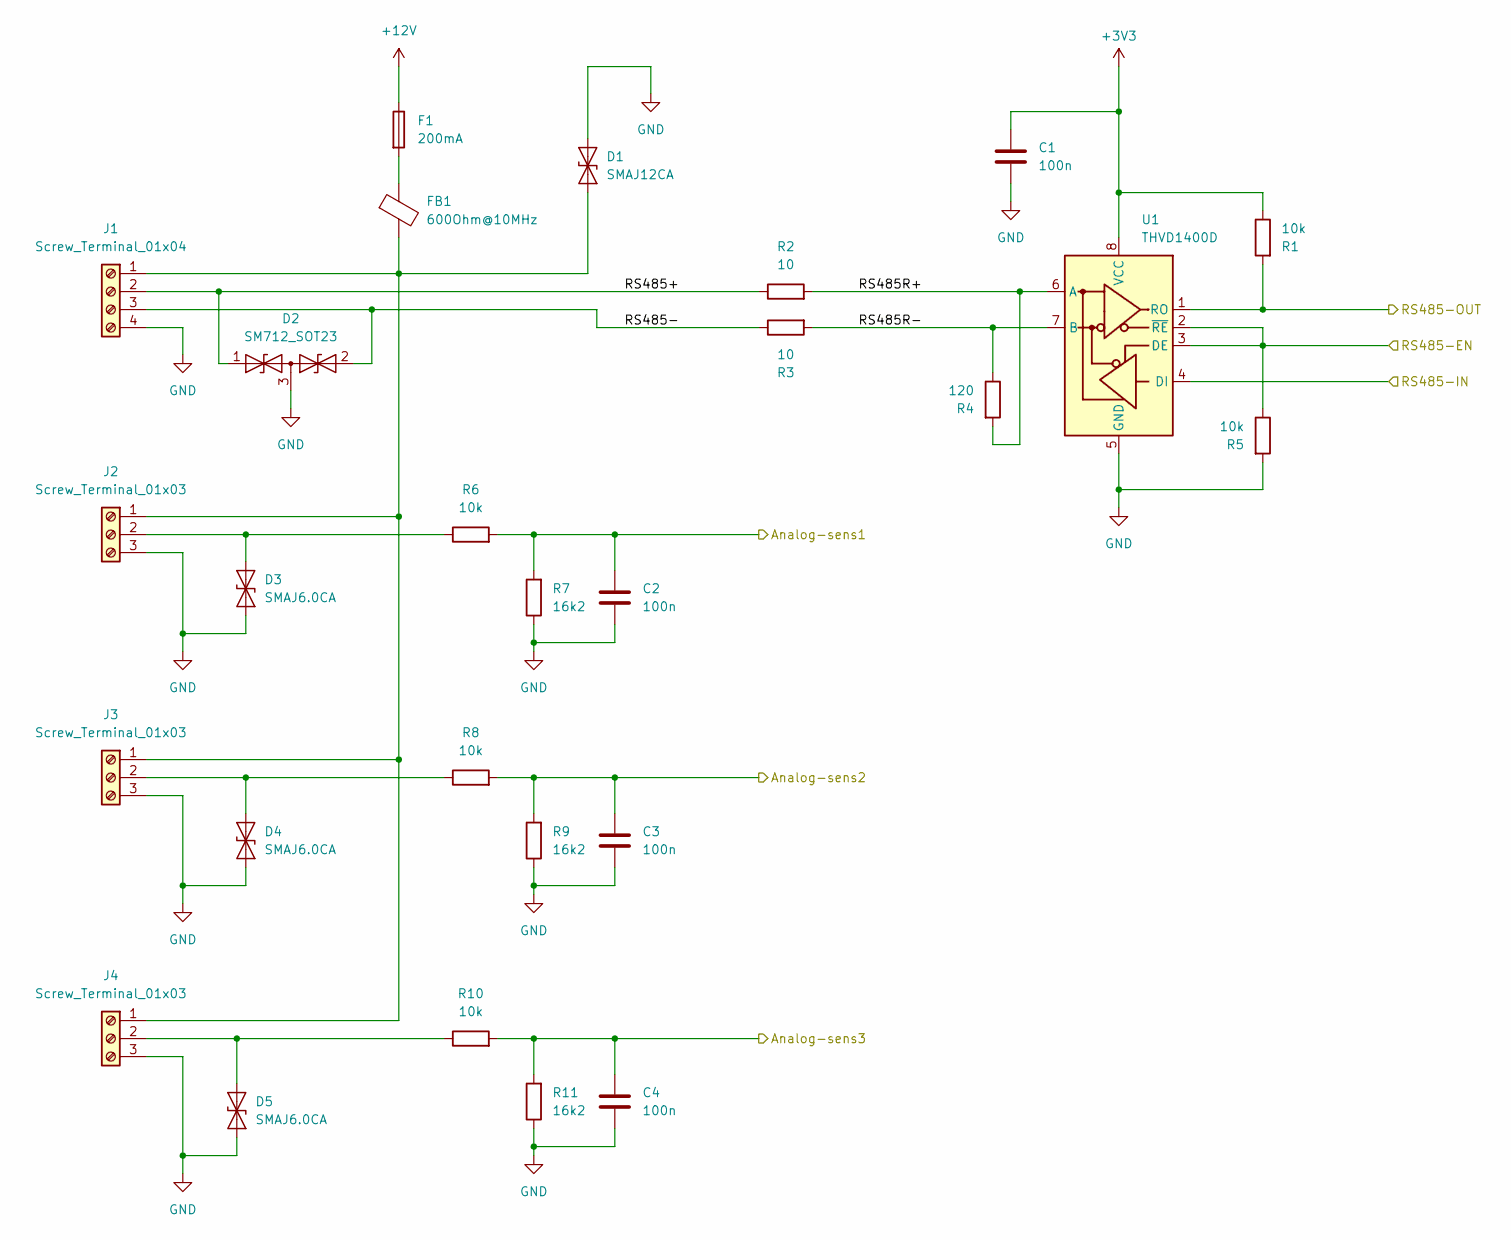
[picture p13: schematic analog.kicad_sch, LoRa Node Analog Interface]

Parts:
C1, C2, C3, C4: 100n; C_0603_1608Metric
D1: SMAJ12CA; D_SMA
D2: SM712_SOT23; SOT-23
D3, D4, D5: SMAJ6.0CA; D_SMA
F1: 200mA; Fuse_0805_2012Metric
FB1: 600Ohm@10MHz; L_0603_1608Metric
J1: Screw_Terminal_01x04; TerminalBlock_Phoenix_MKDS-1,5-4-5.08_1x04_P5.08mm_Horizont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
J2, J3, J4: Screw_Terminal_01x03; TerminalBlock_Phoenix_MKDS-1,5-3-5.08_1x03_P5.08mm_Horizont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
R1, R5, R6, R8, R10: 10k; R_0603_1608Metric
R2, R3: 10; R_0603_1608Metric
R4: 120; R_0603_1608Metric
R7, R9, R11: 16k2; R_0603_1608Metric
U1: THVD1400D; SOIC-8_3.9x4.9mm_P1.27mm

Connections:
+3V3: C1.1, R1.1, U1.8 (VCC); also elsewhere on the board
+12V: F1.1; also elsewhere on the board
/MCU/ADC-CH2: C2.1, R6.2, R7.2; also elsewhere on the board
/MCU/ADC-CH3: C3.1, R8.2, R9.2; also elsewhere on the board
/MCU/ADC-CH4: C4.1, R10.2, R11.2; also elsewhere on the board
/MCU/RS485-EN: R5.1, U1.2 (~RE), U1.3 (DE); also elsewhere on the board
/MCU/UART-RX: R1.2, U1.1 (RO); also elsewhere on the board
/MCU/UART-TX: U1.4 (DI); also elsewhere on the board
/analog/RS485+: D2.1 (A1), J1.2, R2.1
/analog/RS485-: D2.2 (A2), J1.3, R3.1
/analog/RS485R+: R2.2, R4.2, U1.6 (A)
/analog/RS485R-: R3.2, R4.1, U1.7 (B)
GND: C1.2, C2.2, C3.2, C4.2, D1.2 (A2), D2.3 (common), D3.1 (A1), D4.1 (A1), D5.1 (A1), J1.4, J2.3, J3.3, J4.3, R5.2, R7.1, R9.1, R11.1, U1.5 (GND); also elsewhere on the board
unnamed: D1.1 (A1), FB1.2, J1.1, J2.1, J3.1, J4.1
unnamed: D3.2 (A2), J2.2, R6.1
unnamed: D4.2 (A2), J3.2, R8.1
unnamed: D5.2 (A2), J4.2, R10.1
unnamed: F1.2, FB1.1

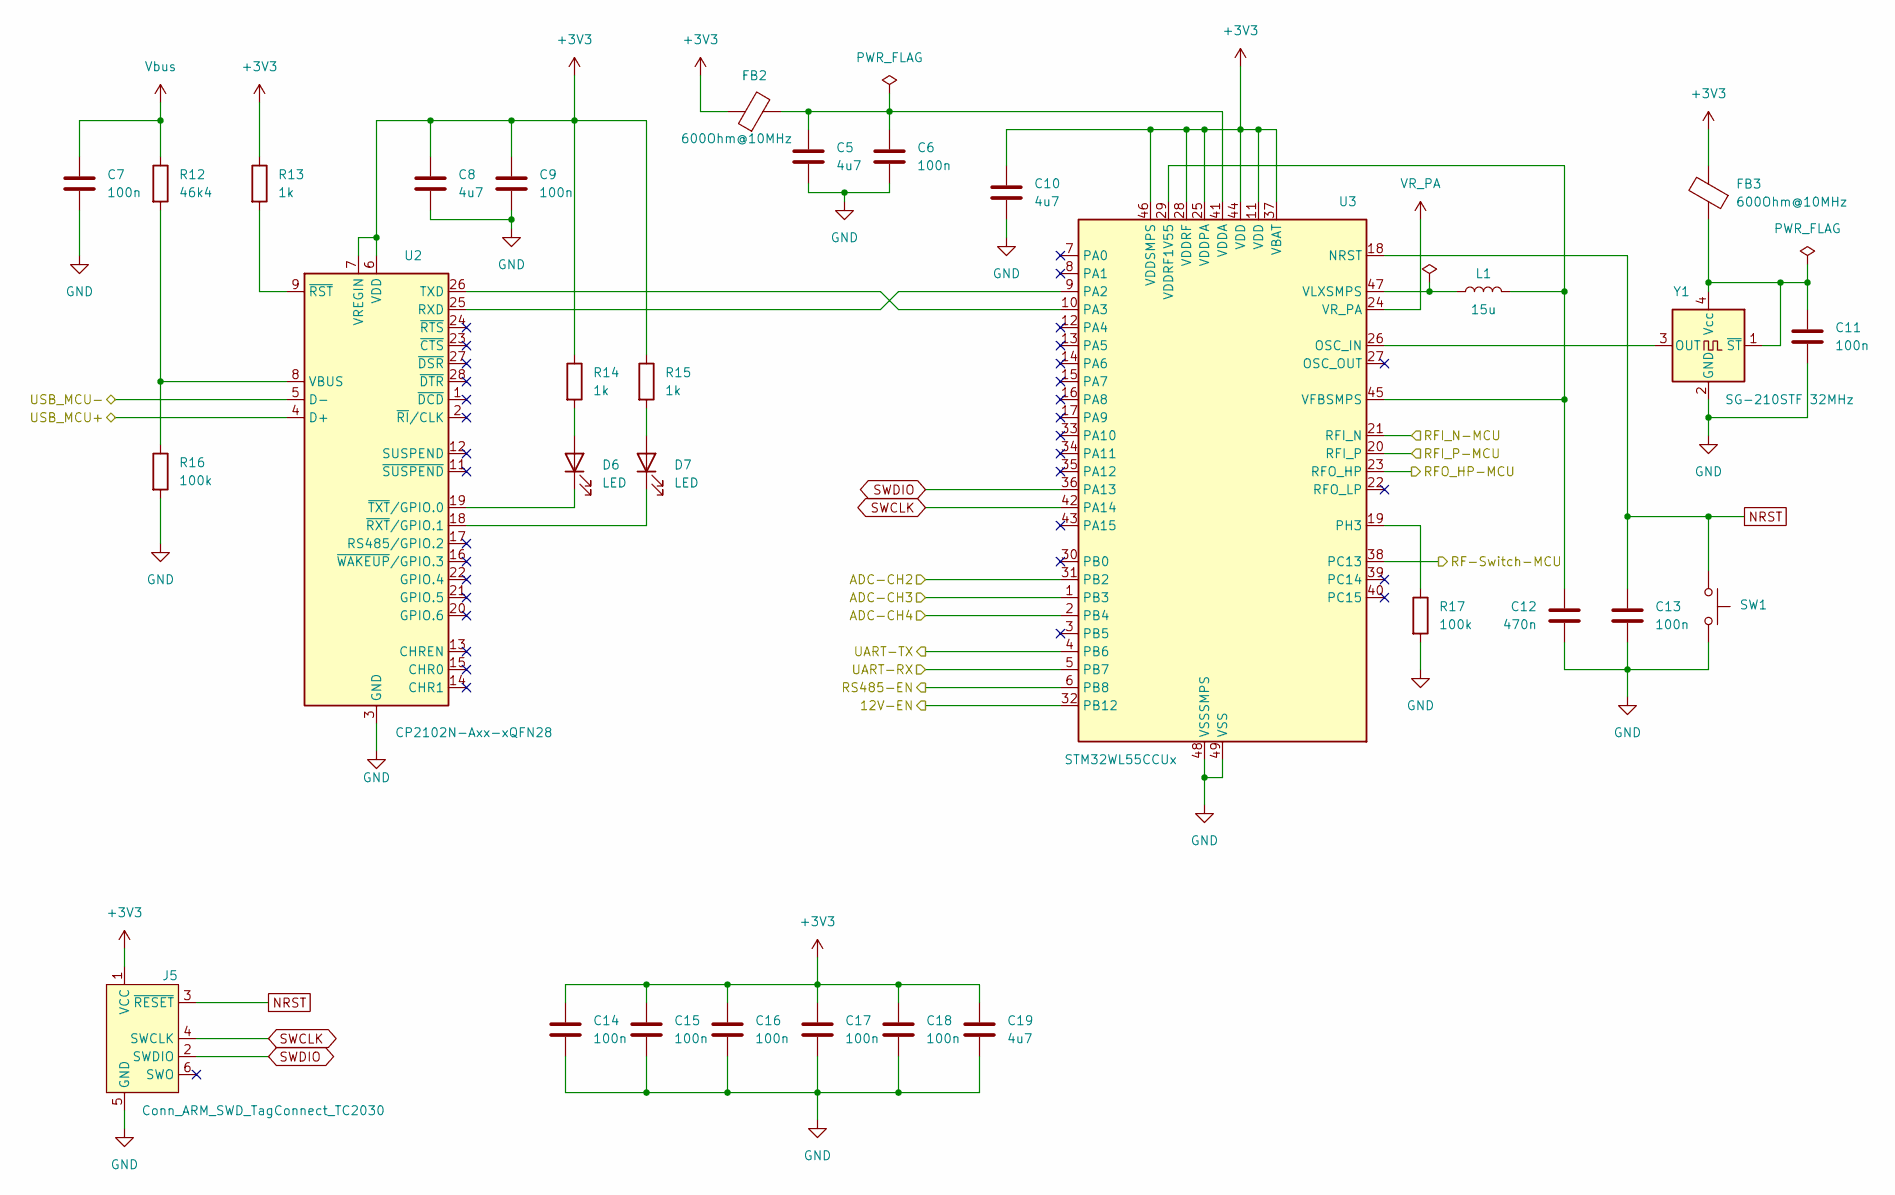
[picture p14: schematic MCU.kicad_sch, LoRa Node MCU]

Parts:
C5, C8, C10, C19: 4u7; C_0603_1608Metric
C6, C7, C9, C11, C13, C14, C15, C16, C17, C18: 100n; C_0603_1608Metric
C12: 470n; C_0603_1608Metric
D6, D7: LED; LED_0603_1608Metric
FB2, FB3: 600Ohm@10MHz; L_0603_1608Metric
J5: Conn_ARM_SWD_TagConnect_TC2030; Tag-Connect_TC2030-IDC-NL_2x03_P1.27mm_Vertical
L1: 15u; L_0805_2012Metric
R12: 46k4; R_0603_1608Metric
R13, R14, R15: 1k; R_0603_1608Metric
R16, R17: 100k; R_0603_1608Metric
SW1: SW_Omron_B3FS; SW_SPST_Omron_B3FS-100xP
U2: CP2102N-Axx-xQFN28; QFN-28-1EP_5x5mm_P0.5mm_EP3.35x3.35mm
U3: STM32WL55CCUx; QFN-48-1EP_7x7mm_P0.5mm_EP5.6x5.6mm
Y1: SG-210STF 32MHz; Oscillator_SMD_SeikoEpson_SG210-4Pin_2.5x2.0mm

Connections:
+3V3: C8.1, C9.1, C10.1, C14.1, C15.1, C16.1, C17.1, C18.1, C19.1, FB2.1, FB3.2, J5.1 (VCC), R13.1, R14.1, R15.1, U2.6 (VDD), U2.7 (VREGIN), U3.11 (VDD), U3.25 (VDDPA), U3.28 (VDDRF), U3.37 (VBAT), U3.44 (VDD), U3.46 (VDDSMPS); also elsewhere on the board
/LoRa RF/RF-Switch: U3.38 (PC13); also elsewhere on the board
/LoRa RF/RFI_N: U3.21 (RFI_N); also elsewhere on the board
/LoRa RF/RFI_P: U3.20 (RFI_P); also elsewhere on the board
/LoRa RF/RFO_HP: U3.23 (RFO_HP); also elsewhere on the board
/MCU/12V-EN: U3.32 (PB12); also elsewhere on the board
/MCU/ADC-CH2: U3.31 (PB2); also elsewhere on the board
/MCU/ADC-CH3: U3.1 (PB3); also elsewhere on the board
/MCU/ADC-CH4: U3.2 (PB4); also elsewhere on the board
/MCU/RS485-EN: U3.6 (PB8); also elsewhere on the board
/MCU/UART-RX: U3.5 (PB7); also elsewhere on the board
/MCU/UART-TX: U3.4 (PB6); also elsewhere on the board
/MCU/USB_MCU+: U2.4 (D+); also elsewhere on the board
/MCU/USB_MCU-: U2.5 (D-); also elsewhere on the board
GND: C5.2, C6.2, C7.2, C8.2, C9.2, C10.2, C11.2, C12.2, C13.2, C14.2, C15.2, C16.2, C17.2, C18.2, C19.2, J5.5 (GND), R16.2, R17.2, SW1.1, U2.3 (GND), U2.29 (GND), U3.48 (VSSSMPS), U3.49 (VSS), Y1.2 (GND); also elsewhere on the board
NRST: C13.1, J5.3 (~RESET), SW1.2, U3.18 (NRST)
unnamed: D6.2 (A), R14.2
unnamed: D6.1 (K), U2.19 (~TXT/GPIO.0)
unnamed: D7.2 (A), R15.2
unnamed: D7.1 (K), U2.18 (~RXT/GPIO.1)
unnamed: U2.25 (RXD), U3.9 (PA2)
unnamed: U2.26 (TXD), U3.10 (PA3)
unnamed: R12.2, R16.1, U2.8 (VBUS)
unnamed: R13.2, U2.9 (~RST)
unnamed: U3.26 (OSC_IN), Y1.3 (OUT)
unnamed: R17.1, U3.19 (PH3)
unnamed: C5.1, C6.1, FB2.2, U3.41 (VDDA)
unnamed: C12.1, L1.2, U3.29 (VDDRF1V55), U3.45 (VFBSMPS)
unnamed: L1.1, U3.47 (VLXSMPS)
unnamed: C11.1, FB3.1, Y1.1 (~ST), Y1.4 (Vcc)
SWCLK: J5.4 (SWCLK), U3.42 (PA14)
SWDIO: J5.2 (SWDIO), U3.36 (PA13)
VR_PA: U3.24 (VR_PA); also elsewhere on the board
Vbus: C7.1, R12.1; also elsewhere on the board

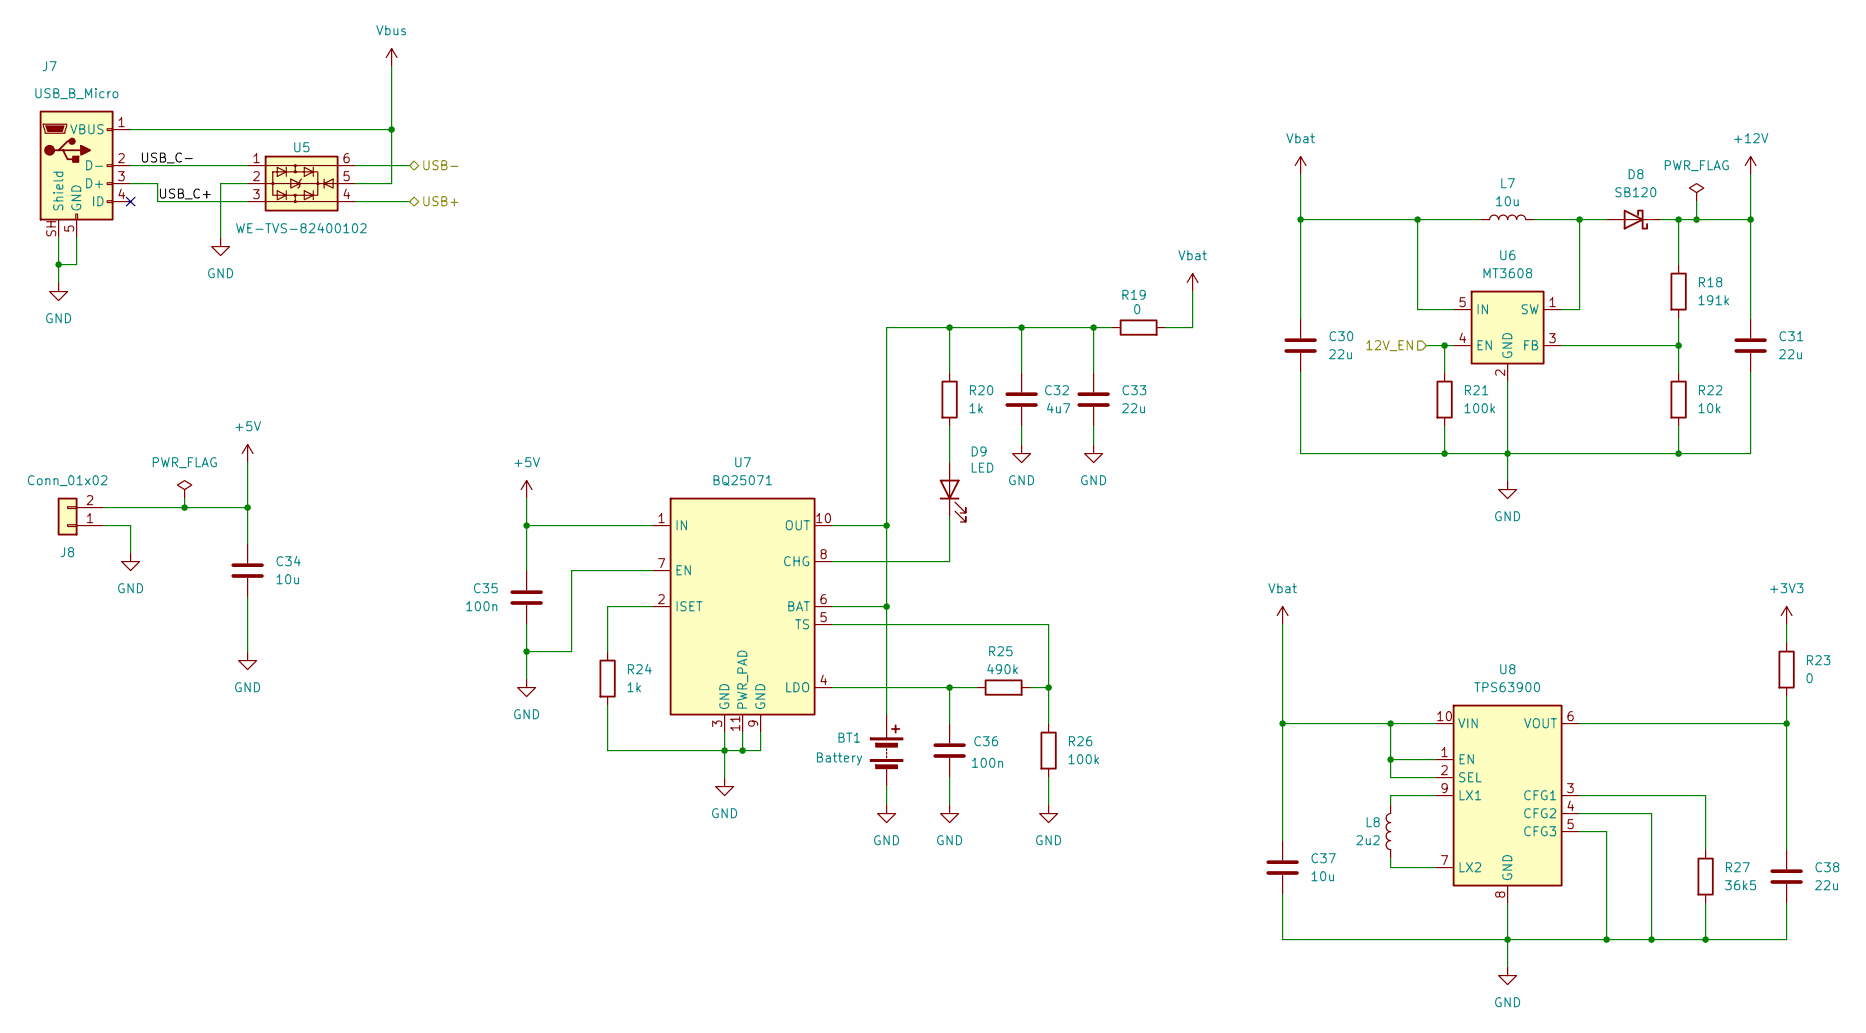
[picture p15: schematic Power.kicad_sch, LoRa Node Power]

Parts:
BT1: Battery; PhoenixContact_MCV_1,5_2-G-3.81_1x02_P3.81mm_Vertical
C30, C31, C33, C38: 22u; C_0603_1608Metric
C32: 4u7; C_0603_1608Metric
C34, C37: 10u; C_0603_1608Metric
C35, C36: 100n; C_0603_1608Metric
D8: SB120; D_SOD-128
D9: LED; LED_0603_1608Metric
J7: USB_B_Micro; Amphenol usb micro connector
J8: Conn_01x02; TerminalBlock_TE_282834-2_1x02_P2.54mm_Horizontal
L7: 10u; L_0805_2012Metric
L8: 2u2; L_0805_2012Metric
R18: 191k; R_0603_1608Metric
R19, R23: 0; R_0603_1608Metric
R20, R24: 1k; R_0603_1608Metric
R21, R26: 100k; R_0603_1608Metric
R22: 10k; R_0603_1608Metric
R25: 490k; R_0603_1608Metric
R27: 36k5; R_0603_1608Metric
U5: WE-TVS-82400102; SOT-23-6_Handsoldering
U6: MT3608; SOT-23-6
U7: BQ25071; WSON-10-1EP_2x3mm_P0.5mm_EP0.84x2.4mm_ThermalVias
U8: TPS63900; WSON-10-1EP_2.5x2.5mm_P0.5mm_EP1.2x2mm_ThermalVias

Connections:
+3V3: R23.1; also elsewhere on the board
+5V: C34.1, C35.1, J8.2, U7.1 (IN)
+12V: C31.1, D8.1 (K), R18.1; also elsewhere on the board
/MCU/12V-EN: R21.1, U6.4 (EN); also elsewhere on the board
/MCU/USB_MCU+: U5.4; also elsewhere on the board
/MCU/USB_MCU-: U5.6; also elsewhere on the board
/Power/USB_C+: J7.3 (D+), U5.3
/Power/USB_C-: J7.2 (D-), U5.1
GND: BT1.2 (-), C30.2, C31.2, C32.2, C33.2, C34.2, C35.2, C36.2, C37.2, C38.2, J7.5 (GND), J7.SH (Shield), J8.1, R21.2, R22.2, R24.2, R26.2, R27.2, U5.2, U6.2 (GND), U7.3 (GND), U7.7 (EN), U7.9 (GND), U7.11 (PWR_PAD), U8.4 (CFG2), U8.5 (CFG3), U8.8 (GND), U8.11 (GND); also elsewhere on the board
unnamed: BT1.1 (+), C32.1, C33.1, R19.1, R20.1, U7.6 (BAT), U7.10 (OUT)
unnamed: D8.2 (A), L7.2, U6.1 (SW)
unnamed: D9.2 (A), R20.2
unnamed: D9.1 (K), U7.8 (CHG)
unnamed: R18.2, R22.1, U6.3 (FB)
unnamed: R24.1, U7.2 (ISET)
unnamed: C36.1, R25.1, U7.4 (LDO)
unnamed: R25.2, R26.1, U7.5 (TS)
unnamed: R27.1, U8.3 (CFG1)
unnamed: L8.1, U8.9 (LX1)
unnamed: L8.2, U8.7 (LX2)
unnamed: C38.1, R23.2, U8.6 (VOUT)
Vbat: C30.1, C37.1, L7.1, R19.2, U6.5 (IN), U8.1 (EN), U8.2 (SEL), U8.10 (VIN)
Vbus: J7.1 (VBUS), U5.5; also elsewhere on the board

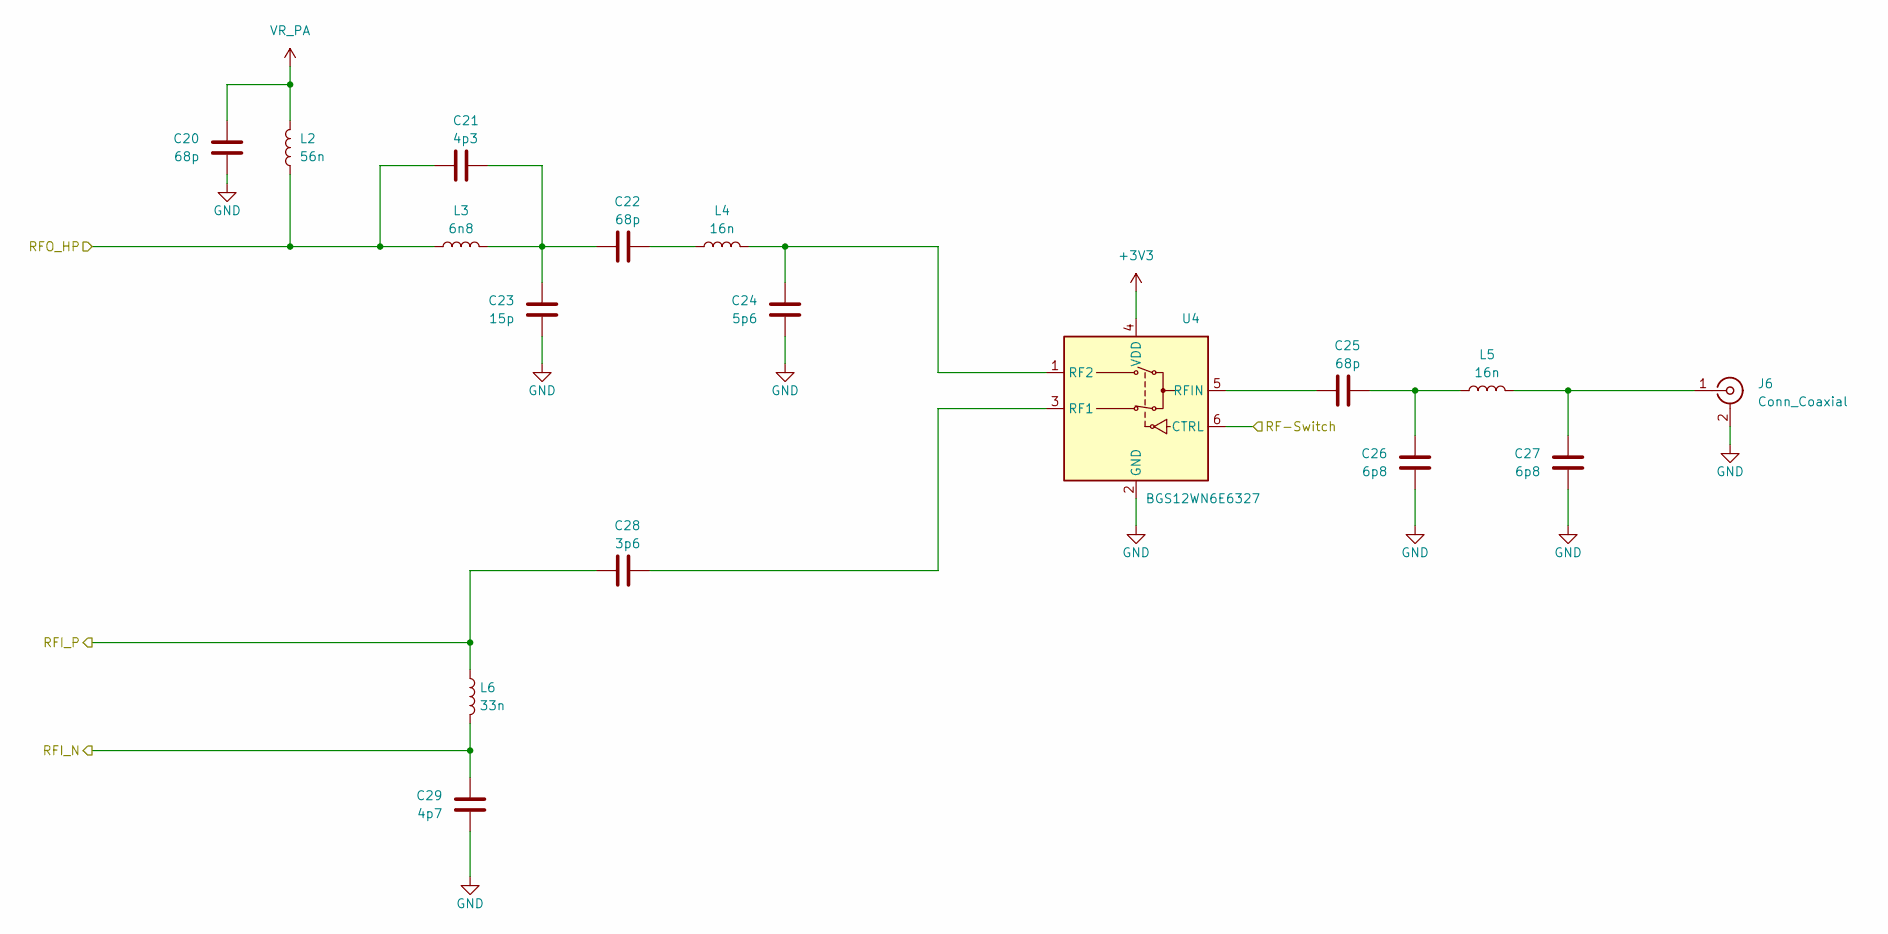
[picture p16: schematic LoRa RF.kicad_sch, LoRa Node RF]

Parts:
C20, C22, C25: 68p; C_0603_1608Metric
C21: 4p3; C_0603_1608Metric
C23: 15p; C_0603_1608Metric
C24: 5p6; C_0603_1608Metric
C26, C27: 6p8; C_0603_1608Metric
C28: 3p6; C_0603_1608Metric
C29: 4p7; C_0603_1608Metric
J6: Conn_Coaxial; BNC_TEConnectivity_1478035_Horizontal
L2: 56n; L_0603_1608Metric
L3: 6n8; L_0603_1608Metric
L4, L5: 16n; L_0603_1608Metric
L6: 33n; L_0603_1608Metric
U4: BGS12WN6E6327; Infineon_PG-TSNP-6-10_0.7x1.1mm_0.7x1.1mm_P0.4mm

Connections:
+3V3: U4.4 (VDD); also elsewhere on the board
/LoRa RF/RF-Switch: U4.6 (CTRL); also elsewhere on the board
/LoRa RF/RFI_N: C29.1, L6.2; also elsewhere on the board
/LoRa RF/RFI_P: C28.1, L6.1; also elsewhere on the board
/LoRa RF/RFO_HP: C21.2, L2.1, L3.1; also elsewhere on the board
GND: C20.2, C23.2, C24.2, C26.2, C27.2, C29.2, J6.2 (Ext), U4.2 (GND); also elsewhere on the board
unnamed: C21.1, C22.1, C23.1, L3.2
unnamed: C22.2, L4.1
unnamed: C25.2, C26.1, L5.1
unnamed: C27.1, J6.1 (In), L5.2
unnamed: C28.2, U4.3 (RF1)
unnamed: C24.1, L4.2, U4.1 (RF2)
unnamed: C25.1, U4.5 (RFIN)
VR_PA: C20.1, L2.2; also elsewhere on the board

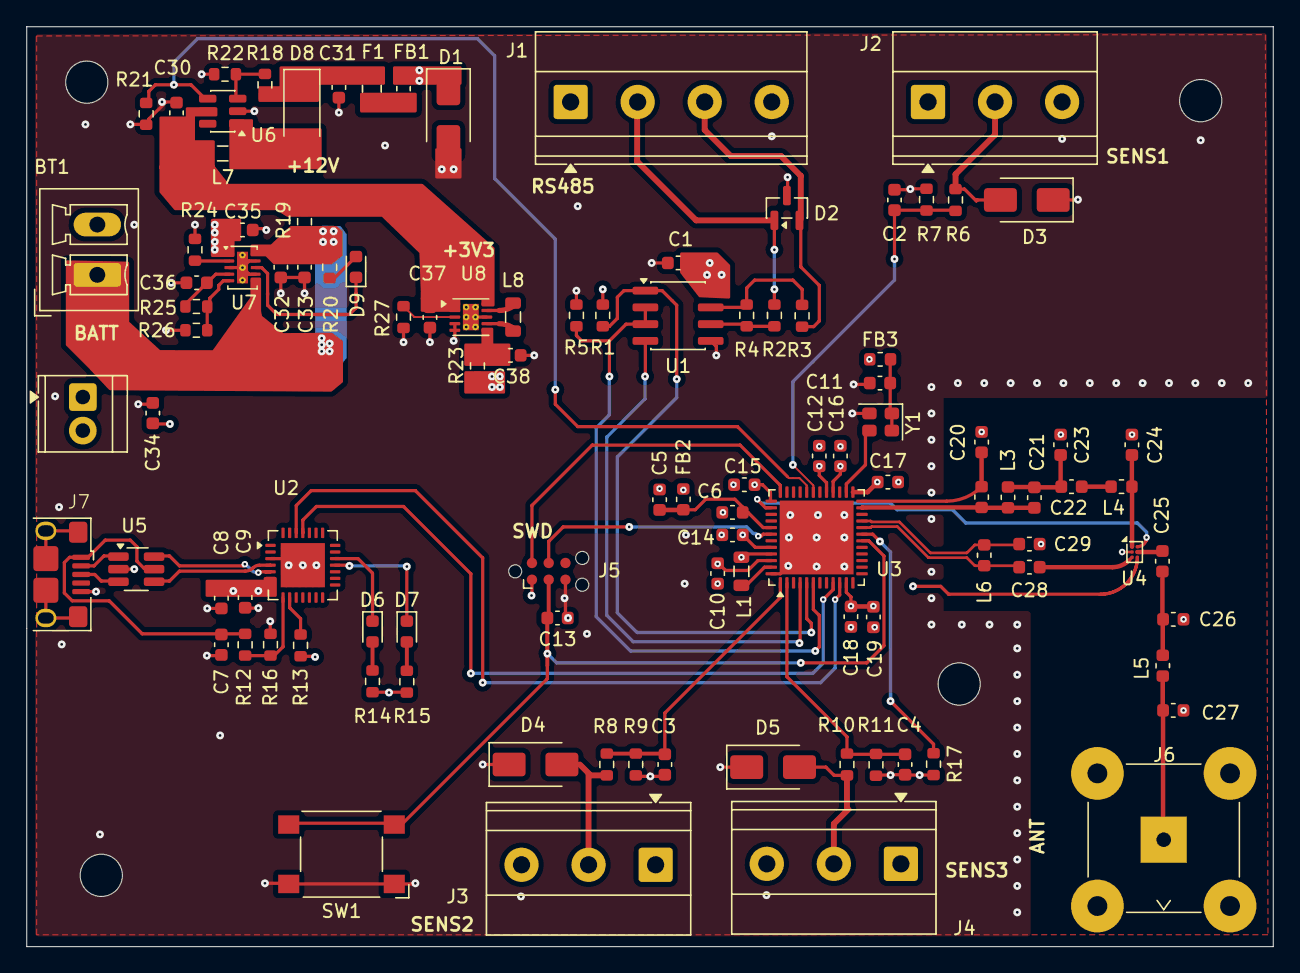
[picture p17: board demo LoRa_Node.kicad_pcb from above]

Board: 4 copper layers, 94.5 x 69.7 mm, 105 parts (0 on the bottom side), 67 nets.

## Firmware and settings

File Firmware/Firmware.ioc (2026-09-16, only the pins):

Mcu.UserName=STM32WL55JCIx
PA2.Signal=USART2_TX
PA3.Signal=USART2_RX
PB0-VDD_TCXO.Signal=VDDTCXO
PB13.Signal=ADC_IN0
PB14.Signal=ADC_IN1
PB3.Signal=ADC_IN2
PC13.GPIO_Label=EN_12V_DCDC
PC13.Signal=GPIO_Output
PC14-OSC32_IN.GPIO_Label=RCC_OSC32_IN
PC14-OSC32_IN.Signal=RCC_OSC32_IN
PC15-OSC32_OUT.GPIO_Label=RCC_OSC32_OUT
PC15-OSC32_OUT.Signal=RCC_OSC32_OUT
PC3.GPIO_Label=FE_CTRL3
PC3.Signal=GPIO_Output
PC4.GPIO_Label=FE_CTRL1
PC4.Signal=GPIO_Output
PC5.GPIO_Label=FE_CTRL2
PC5.Signal=GPIO_Output

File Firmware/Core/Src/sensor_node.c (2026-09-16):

#include "sensor_node.h"

#include <stddef.h>
#include <string.h>

#include "app_config.h"
#include "signal_processing.h"
#include "stm32_timer.h"
#include "sys_app.h"
#include "telemetry.h"
#include "utilities_def.h"

#define ADC_EVENT_HALF   (1UL << 0)
#define ADC_EVENT_FULL   (1UL << 1)
#define ADC_EVENT_ERROR  (1UL << 2)

static SensorNodePlatform_t platform_api;
static SensorNodeState_t state;
static UTIL_TIMER_Object_t acquisition_timer;
static UTIL_TIMER_Object_t warmup_timer;
static uint16_t adc_dma_buffer[APP_ADC_DMA_BUFFER_SAMPLES];
static volatile uint32_t adc_events;
static volatile bool acquisition_due;
static volatile bool warmup_elapsed;
static uint32_t processed_samples;

UTIL_TIMER_Status_t create_status;
UTIL_TIMER_Status_t start_status;

static void AcquisitionTimerCallback(void *context)
{
  (void) context;
  acquisition_due = true;
}

static void WarmupTimerCallback(void *context)
{
  (void) context;
  warmup_elapsed = true;
}

static uint32_t TakeAdcEvents(void)
{
  uint32_t events;

  UTILS_ENTER_CRITICAL_SECTION();
  events = adc_events;
  adc_events = 0U;
  UTILS_EXIT_CRITICAL_SECTION();

  return events;
}

static void FinishAcquisition(void)
{
  if (platform_api.AdcStopDma != NULL)
  {
    platform_api.AdcStopDma();
  }
  state = SENSOR_NODE_PROCESSING;
  APP_LOG(TS_ON, VLEVEL_M, "Stop  acquisition\r\n");
}

static void ProcessAdcBlock(const uint16_t *samples, uint32_t available_samples)
{
  uint32_t remaining_samples = APP_ACQUISITION_TOTAL_SAMPLES - processed_samples;
  uint32_t samples_to_process = (available_samples < remaining_samples) ?
                                available_samples : remaining_samples;

  if (samples_to_process != 0U)
  {
    SignalProcessing_ProcessBlock(samples, samples_to_process);
    processed_samples += samples_to_process;
  }
}

void SensorNode_Init(const SensorNodePlatform_t *platform)
{
  APP_LOG(TS_ON, VLEVEL_M, "Sensor initialization\r\n");

  memset(&platform_api, 0, sizeof(platform_api));
  if (platform != NULL)
  {
    platform_api = *platform;
  }

  SignalProcessing_Init();
  state = SENSOR_NODE_IDLE;
  acquisition_due = false;
  warmup_elapsed = false;
  adc_events = 0U;

  create_status = UTIL_TIMER_Create(&acquisition_timer, APP_ACQUISITION_PERIOD_MS,
                    UTIL_TIMER_PERIODIC, AcquisitionTimerCallback, NULL);
  UTIL_TIMER_Create(&warmup_timer, APP_SENSOR_WARMUP_MS,
                    UTIL_TIMER_ONESHOT, WarmupTimerCallback, NULL);
  start_status = UTIL_TIMER_Start(&acquisition_timer);

  APP_LOG(TS_ON, VLEVEL_M, "Acq timer start=%d start=%d running=%u\r\n",
          create_status,
          start_status, 
          (unsigned int)UTIL_TIMER_IsRunning(&acquisition_timer));
}

void SensorNode_Process(void)
{
  switch (state)
  {
    case SENSOR_NODE_IDLE:
      if (acquisition_due)
      {
        acquisition_due = false;
        if (platform_api.SensorPowerSet != NULL)
        {
          platform_api.SensorPowerSet(true);
        }
        UTIL_TIMER_SetPeriod(&warmup_timer, APP_SENSOR_WARMUP_MS);
        UTIL_TIMER_Start(&warmup_timer);
        state = SENSOR_NODE_WARMUP;
        APP_LOG(TS_ON, VLEVEL_M, "Start sensor warmup\r\n");
      }
      break;

    case SENSOR_NODE_WARMUP:
      if (warmup_elapsed)
      {
        warmup_elapsed = false;
        processed_samples = 0U;
        adc_events = 0U;
        SignalProcessing_Reset();

        if ((platform_api.AdcStartDma == NULL) ||
            !platform_api.AdcStartDma(adc_dma_buffer, APP_ADC_DMA_BUFFER_SAMPLES))
        {
          state = SENSOR_NODE_ERROR;
        }
        else
        {
          state = SENSOR_NODE_ACQUISITION;
          APP_LOG(TS_ON, VLEVEL_M, "Starting acquisition\r\n");
        }
      }
      break;

    case SENSOR_NODE_ACQUISITION:
    {
      uint32_t events = TakeAdcEvents();

      if ((events & ADC_EVENT_ERROR) != 0U)
      {
        state = SENSOR_NODE_ERROR;
        break;
      }
      if ((events & ADC_EVENT_HALF) != 0U)
      {
        ProcessAdcBlock(&adc_dma_buffer[0], APP_ADC_DMA_HALF_SAMPLES);
        APP_LOG(TS_ON, VLEVEL_M, "Half data processed\r\n");
      }
      if (((events & ADC_EVENT_FULL) != 0U) &&
          (processed_samples < APP_ACQUISITION_TOTAL_SAMPLES))
      {
        ProcessAdcBlock(&adc_dma_buffer[APP_ADC_DMA_HALF_SAMPLES], APP_ADC_DMA_HALF_SAMPLES);
        APP_LOG(TS_ON, VLEVEL_M, "Full data processed\r\n");
      }
      if (processed_samples >= APP_ACQUISITION_TOTAL_SAMPLES)
      {
        FinishAcquisition();
      }
      break;
    }

    case SENSOR_NODE_PROCESSING:
    {
      SignalStatistics_t statistics;
      uint32_t timestamp = (platform_api.GetTimeMs != NULL) ? platform_api.GetTimeMs() : 0U;

      SignalProcessing_Finalize(&statistics);
      if (!Telemetry_Update(timestamp, &statistics))
      {
        APP_LOG(TS_ON, VLEVEL_M, "Telemetry batch still pending; acquisition not stored\r\n");
      }

      if (platform_api.SensorPowerSet != NULL)
      {
        platform_api.SensorPowerSet(false);
      }
      APP_LOG(TS_ON, VLEVEL_M, "Acquisition complete: %lu samples\r\n",
              statistics.input_sample_count[0]);

      APP_LOG(TS_ON, VLEVEL_M, "misured voltage reference: %lu\r\n", statistics.mean[3]);
      state = SENSOR_NODE_IDLE;
      break;
    }

    case SENSOR_NODE_ERROR:
    default:
      if (platform_api.AdcStopDma != NULL)
      {
        platform_api.AdcStopDma();
      }
      if (platform_api.SensorPowerSet != NULL)
      {
        platform_api.SensorPowerSet(false);
      }
      APP_LOG(TS_ON, VLEVEL_M, "Sensor node acquisition error\r\n");
      state = SENSOR_NODE_IDLE;
      break;
  }
}

SensorNodeState_t SensorNode_GetState(void)
{
  return state;
}

void SensorNode_OnAdcHalfComplete(void)
{
  adc_events |= ADC_EVENT_HALF;
}

void SensorNode_OnAdcComplete(void)
{
  adc_events |= ADC_EVENT_FULL;
}

void SensorNode_OnAdcError(void)
{
  adc_events |= ADC_EVENT_ERROR;
}

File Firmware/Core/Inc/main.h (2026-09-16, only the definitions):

#define RTC_N_PREDIV_S 10
#define RTC_PREDIV_S ((1<<RTC_N_PREDIV_S)-1)
#define RTC_PREDIV_A ((1<<(15-RTC_N_PREDIV_S))-1)
#define RTC_N_PREDIV_S 10
#define RTC_PREDIV_S ((1 << RTC_N_PREDIV_S) - 1)
#define RTC_PREDIV_A ((1 << (15 - RTC_N_PREDIV_S)) - 1)
#define RCC_OSC32_IN_Pin GPIO_PIN_14
#define RCC_OSC32_IN_GPIO_Port GPIOC
#define RCC_OSC32_OUT_Pin GPIO_PIN_15
#define RCC_OSC32_OUT_GPIO_Port GPIOC
#define EN_12V_DCDC_Pin GPIO_PIN_13
#define EN_12V_DCDC_GPIO_Port GPIOC
#define FE_CTRL3_Pin GPIO_PIN_3
#define FE_CTRL3_GPIO_Port GPIOC
#define FE_CTRL2_Pin GPIO_PIN_5
#define FE_CTRL2_GPIO_Port GPIOC
#define FE_CTRL1_Pin GPIO_PIN_4
#define FE_CTRL1_GPIO_Port GPIOC

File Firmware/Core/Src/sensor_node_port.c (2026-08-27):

#include "sensor_node_port.h"

#include <stdbool.h>
#include <stdint.h>

#include "main.h"
#include "sensor_node.h"

extern ADC_HandleTypeDef hadc;
extern TIM_HandleTypeDef htim2;

static void SensorPowerSet(bool enabled)
{
  HAL_GPIO_WritePin(EN_12V_DCDC_GPIO_Port, EN_12V_DCDC_Pin,
                    enabled ? GPIO_PIN_SET : GPIO_PIN_RESET);
}

static bool AdcStartDma(uint16_t *buffer, uint32_t sample_count)
{
  if (HAL_ADC_Start_DMA(&hadc, (uint32_t *) buffer, sample_count) != HAL_OK)
  {
    return false;
  }

  if (HAL_TIM_Base_Start(&htim2) != HAL_OK)
  {
    (void) HAL_ADC_Stop_DMA(&hadc);
    return false;
  }

  return true;
}

static void AdcStopDma(void)
{
  (void) HAL_TIM_Base_Stop(&htim2);
  (void) HAL_ADC_Stop_DMA(&hadc);
}

static uint32_t GetTimeMs(void)
{
  return HAL_GetTick();
}

void SensorNodePort_Init(void)
{
  static const SensorNodePlatform_t platform =
  {
    .SensorPowerSet = SensorPowerSet,
    .AdcStartDma = AdcStartDma,
    .AdcStopDma = AdcStopDma,
    .GetTimeMs = GetTimeMs
  };

  SensorNode_Init(&platform);
}

void HAL_ADC_ConvHalfCpltCallback(ADC_HandleTypeDef *adc)
{
  if (adc == &hadc)
  {
    SensorNode_OnAdcHalfComplete();
  }
}

void HAL_ADC_ConvCpltCallback(ADC_HandleTypeDef *adc)
{
  if (adc == &hadc)
  {
    SensorNode_OnAdcComplete();
  }
}

void HAL_ADC_ErrorCallback(ADC_HandleTypeDef *adc)
{
  if (adc == &hadc)
  {
    SensorNode_OnAdcError();
  }
}

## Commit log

2026-08-23 Hardware Rev. B
    [LoRa RF.kicad_sch, MCU.kicad_sch, Power.kicad_sch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]
2026-08-30 added debug traces
2026-08-30 changed signal processing path ADC->IIR->mean independent for each channel
2026-08-30 enabled SubGHz Radio interrupt
2026-09-01 removed IIR LP filter
2026-09-01 removed IIR LP filter and ajusted ADC sampling frequency
2026-09-01 changed LP anti-aliasing filter to 2nd order RC
    [analog.kicad_sch]
2026-09-15 anti-aliasing filter update
2026-09-16 fix: make clock configuration compatible with STOP2
    [Firmware.ioc, app_config.h, main.h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]

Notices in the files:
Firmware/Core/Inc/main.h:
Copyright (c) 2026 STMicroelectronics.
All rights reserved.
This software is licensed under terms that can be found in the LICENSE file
